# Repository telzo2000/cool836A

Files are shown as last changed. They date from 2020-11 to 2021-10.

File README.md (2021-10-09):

# cool836A
ブラックバージョン(Ver.A)のbuilde guideはこちらです。<br>
https://github.com/telzo2000/cool836A/blob/master/buildguide_black.md
<br>
レッドバージョン(Ver.B+)のbuilde guideはこちらです。<br>
https://github.com/telzo2000/cool836A/blob/master/buildguide_red.md
<br>
イエローバージョン(Ver.C+)のbuilde guiadeはこちらです。<br>
https://github.com/telzo2000/cool836A/blob/master/buildguide_yellow.md
<br>

# 設計に至るまで（Up to the design）
<br>
平成31年度および令和元年度に、「自作キーボード」という語を知りました。<br>
その後、nomu30、Choco60、Caravelle等を購入して実際に作ってみました。<br>
これらはどれもとても素晴らしいキーボードでした。<br>
次にSU120を知り、文系の自分でもなんとか自作キーボードが作れるのではないかと考えるようになりました。<br>
実際、SU120をTALP KEYBOARDさんで購入して、それを使って30%キーボード「My First Mini」を作りました。<br>
なかなかうまくいなかい部分があり、その際にはSU120の作者さんから助言をもらい、
完成に至りました。<br>
この経験を積んで、さらにSU120を使い、Caravelleのあまったスイッチプレートを活用した「Caravellion」を作りました。<br>
「Caravellion」と同時期に、格子配列の30％キーボード
[cool635](https://github.com/telzo2000/cool635-) 
を作りました。<br>
さらに30％キーボードに、矢印キーや数字キーが欲しいと思い始めて、50％キーボード「cool753」を作りました。<br>
これらはすべてSU120を使って作りました。<br>
ここまで経験すると、ある程度、わかってきたもので、次は何を作ろうかなと思い、
何となく知ったAlice配列という言葉が気になり、多分Alice配列っぽいだろうと考えて作ったのは、
30％キーボードの「cool836A」です。<br>
これは令和２年度の７月に、４連休を利用して一気に作りました。<br>
ただ、レイアウトについては事前に、角度を５〜10の間で試行錯誤しています。<br>
これまでの経験から、ケースはMDF材ですばやく加工することができるようになりました。<br>
ただ、私の技術では、木材で作成すると、やや大きくなってしまいます。<br>
cool635の作成で、kicadの使い方も少しわかってきたので、cool836Aも最初はSU120で作り、
次にkicadでPCBの設計をしました。<br>２度のPCBを発注しました。<br>
１度目は基板部分のみ、２度目は基板、トッププレート、ボトムプレートをまとめたもの。<br>
試作用cool836Aは１度目の基板部分のみに、発注先のミスにより余分に頂いたボトムプレートから成るものです。<br>
頒布用cool836Aは２度目のまとめたものに成るものです。発注したPCBが黒色だったため、通称「ブラックバージョン」としています。<br>
「レッドバージョン」は、MXソケットを採用しました。pro microとの部品干渉から、一部のキースイッチは前後向きを変えました。<br>
PCDの下面にLEDを追加できるよう端子を加えましたが、まだQMKの理解が進んでいないため、私自身は使えません。<br>
発注先の問題より、イエローバージョンの到着に１ヶ月かかりました。仮組みした段階で、複数の課題が見つかりました。<br>
1つ目はpro microの位置が2mmぐらいの差でコンスルーの足とキースイッチの端が干渉しています。<br>
2つ目は、ケーブルをつなぐ間口が狭かったことです。細いケーブルであれば問題ありませんが、私が普段使っているケーブルだと干渉してしまい刺さりません。<br>
将来の予定としては、イエローバージョンの修正版を発注するつもりです。その際、合わせてレッドバージョンを黒色で発注するつもりです。<br>
12月27日に、レッドバージョンの黒色として、一部のネジ穴（M２スペーサー）の大きさを修正したVer.Dを発注しました。これに合わせてアクリルでのトッププレート、ボトムプレートも発注しました。<br>
令和３年１月上旬に、Boothにてイエローバージョン、アクリルプレートをそれぞれ頒布した。
令和３年１月中旬、フライングオニオオハシ氏（＠oha_oha_Ohashi）により、qmk_firmwareへのマージがなされ、qmk configuratorでもキーレイアウトの変更が可能となった。フライングオニオオハシ氏、本当にありがとうございました。<br>
余談ですが、一部の修正をラズパイで行うことができました。<br>
しばらくcool836Aについてのアップデートをしませんでした。ブルートゥースに向けて試行錯誤をしましたが、まだ成功していません。<br>
cool943Sの開発が終わり、発注した後、時間ができたので、ラージサイズのcool836Aを設計しました。当初、Alice配列の分割キーボードを想定していました。しかし、それより先に一体型を作ろうと思い、ラージサイズ版のcool836A、正式には[cool844](https://github.com/telzo2000/cool844)となり、44キーの40％キーボードとなりました。そのケースについては、GH60系のケースが使えるように設計しました。MCU直付けの基板を作るのはちょっと難しく、ちょっとした工夫で乗り切ろうとしています。令和3年2月22日に発注しました。<br>
（令和３年10月）Raspberry財団がRaspberry Pi Picoという、安価な部品を作ったので、それを使ったcool836Aを設計した。<br>
 pro microよりも、Picoのほうがやや長く、幅もやや広いため、従来の設置場所では困難と感じたため、設置場所を変更して設計した。それに合わせて配線の見直しをしました。これまでcol,rowで6x6で組んでいた部分を、12x3で組んでみました。特に問題なく、やや配線が綺麗にできたというところです。<br>
 Raspberry Pi PIco採用のcool836Aを、cool836Picoと名付けて、kmkによるpythonで、それと別にprkによるrubyで、それぞれファームウェアを作成した。この時点では、qmkが大きく先んじている。kmkもprkも、期待した以上に使い勝手が良くない。レイヤーキーあたりの反応がちょっとゆっくりと感じている。もう少し洗練されないと、日常使う気持ちになれない。ただ、ハード的なことはわかったので、今後、cool836A以外にも、Raspberry Pi Picoを使った自作キーボードを設計しようと思う。

# 今後の変更予定（Update Plan)
順不同<br>
☑︎REMAP対応に向けて、via用jsonファイル、hexファイルの作成<br>
※この」リポジトリ内にあります。ご自由にお使いください。<br>
☑MXソケット採用 Ver.B Date:20201024<br>
☑︎chocoスイッチ版　※pro microの設置場所をPCBの下面から上面に変更か<br>
☑LED装着　Ver.B+ Date:20201025<br>
※装着して点灯を確認。（2020/12/25）<br>
□pro micro→MCU直付<br>
☑アクリルのトッププレート、ボトムプレート　※試作PCBの余剰分（３枚）に使用するか。（2020/11/14）<br>
※Ver.Dで発注した。（2020/12/27）<br>
□アクリル密閉型ケース<br>
☑ラージ版（仮称cool840A）※ラージ版のcool836Aはcool844という名称となりました。[別のリポジトリ](https://github.com/telzo2000/cool844/blob/main/README.md)にまとめました。<br>
☑薄型への挑戦（pro microの位置変更）※イエローバージョンとして計画中(2020/11/10)<br>
□iPhone固定できるケースをオプションとして作る（アクリルか？）<br>
□Bluetooth採用※よくわかっていませんが、イエローバージョンまでならば、多分電池を収納するスペースがあるだろうと考えました。思いつきです。青色にして「ブルーバージョン」となるかな。<br><br>
☑BLE micro使用時の電池ケース収納部分を追加（2020/11/11）※イエローバージョンで実装済み。<br>
☑︎Raspberry pi picoに対応したバージョン<br>

# 発注ガーバーファイル名
試作　gbr　（20200812）<br>
Ver.A gbr20200901　通称「ブラックバージョン」<br>
Ver.B+ gbr20201025　通称「レッドバージョン」<br>
Ver.C+ gbr20201114　通称「イエローバージョン」<br>
Ver.D　gbr20201227plate,gbr20201227pcb,gbr20201227case<br>
cool844 Ver.1 gbrcool844date20210222 通称「cool836Aラージサイズ」<br>

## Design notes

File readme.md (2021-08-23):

# cool836A

- このプロジェクトの詳細については設計者たる[m.ki様](https://twitter.com/0002ozlet)による[GitHubリポジトリ](https://github.com/telzo2000/cool836A)の記述をご覧ください。

### バージョン(A, B+, C+)について
- m.ki様によるとどのバージョンも回路は同じで、ファームウェアを分ける必要はないとのことです。
- しかしながらこのファームウェアは、cool836A ver.B+ (通称レッドバージョン)のみでテストされています(2021年1月7日現在)。そのため念のため、当面の間はサブフォルダの名前をcool836A/verB_REDとさせていただきます。
- ほかのバージョンに書き込んだときに不具合等がありましたら、方はお気軽に私[オオハシ](https://twitter.com/oha_oha_Ohashi)までご連絡ください。

## 申し訳程度のチュートリアル
詳細に書き込む労力は払えませんでしたが、最低限のコードのみ記します。

git clone のあと、

``` make cool836A/verB_RED:default ```

でコンパイル可能であることを確認し、

``` make cool836A/verB_RED:default:avrdude ```

によってデフォルトキーマップをPro Microに焼けるかもしれません。
`default`の代わりに`Ohasheen`を利用することもできます。

初心者の方はもっと素晴らしいウェブサイトでGitやqmk firmwareの使い方を覚えていただくのがよいかと思います。

-----------------
## English
- [Here](https://github.com/telzo2000/cool836A) are a full description of this project and build guide by the great Designer: [m.ki](imgur.com image replace me!)

- Each virsions(A, B+, C+) of cool836A has the same circuit and that means you can install this firmware on any of them.
- However, this repository is currently(Jan 7, 2021) tested on ver.B+ (RED version) only. Feel free to contact [ME](https://github.com/ketcha-k) for any problems.

- firmware maintainer: [Ohashi](https://github.com/ketcha-k)

## Such a humble tutorial
The author would like to provide a minimum guide.

After cloning the repository, you may want to 

``` make cool836A/verB_RED ```

to make sure it's compilable, and 

``` make cool836A/verB_RED:default ```

which leads you to the goal.

It is recommended that beginners learn how to get started with qmk firmware/configurator at other fantastic websites rather than here......

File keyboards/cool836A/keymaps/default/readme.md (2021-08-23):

# m.ki様によるデフォルトキーマップ

[レッドバージョン　ビルドガイド](https://github.com/telzo2000/cool836A/blob/master/buildguide_red.md)で紹介されていたキーマップです。チートシートを見ながらコードに書き写しました。

-------
## チートシート
以下、[同ページ](https://github.com/telzo2000/cool836A/blob/master/buildguide_red.md)の画像のコピーを添付します。
+ Layer=0
Layer=0
+ Layer=1
Layer=1
+ Layer=2
Layer=2
+ Layer=3
Layer=3

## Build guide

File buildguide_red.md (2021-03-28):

# レッドバージョン　ビルドガイド

**写真**



<br>
<br>
**特徴**
<br>
・30％Alice  layout<br>
・サンドイッチマウント、チルト0〜10度<br>
・PCB、トッププレート、ボトムプレートそれぞれFR4を使用。<br>
・36キー（MXソケットによるキースイッチ交換可能）<br>
<br>

**同封されている部品**
<br>
１　PCB　１枚<br>
２　トッププレート　１枚<br>
３　ボトムプレート１式（４枚）<br>
４　ダイオード　40個（予備４個を含む）<br>
５　タクトスイッチ　１個<br>
６　ネジ（M2 4mm）　　７本<br>
７　ネジ（M2 8mm）　　７本<br>
８　スペーサー（M2 10mm）　７本<br>
９　クッションゴム　４個<br>
１０　MXソケット　40個（予備４個を含む）<br>
<br>

**別途、購入が必要な部品**
<br>
１　キースイッチ　36個<br>
２　キーキャップ　36個 ※１<br>
３　pro micro １個<br>
４　コンスルー（スプリングピンヘッダ）　１組（２個）<br>
※１　キーキャップの構成は、1U×32、1.25U×2、1.5U×1、1.75U×1ですが、全て1Uキーでも構いません。<br>
　　　キーキャップのレジェンド（キーキャップ上面の印字）とキーレイアウトのキーのサイズが一致しません。<br>
　　　レジェンドよりも使い勝手のよいキーレイアウトを優先しています。<br>
　　　<br>
**ファームウェア**
<br>
　「ハンダ付け不要版」では、すでに同封のpro microにファームウェアが書き込まれています。<br>
　このキーボードはQMKというキーボード用のソフトウェアで動作するようにプログラミングしています。<br>
　従来、頒布を目的としていなかったことと、作者が非IT系であることから、自力でファームウェアを作成していません。[Keyboard Firmware builder](https://kbfirmware.com/)を利用して、hexファイルを作成しました。[QMK Configurator](https://config.qmk.fm/#/)にプルリクする等すれば、QMKConfiguratorを使用してキーレイアウトを変更できますが、作者には、その力がありません。有識者の方で出来る方がいらっしゃれば、よろしくお願いします。<br>
　（もし、出来ましたら、ご連絡いただけると、ビルドガイドに、そのことを記載したいと思います）<br>
<br>
追記（令和３年１月16日）<br>
フライングオニオオハシ氏（＠oha_oha_Ohashi）によりqmk_firmwareへの公式マージがされました。そして、[QMK Configurator](https://config.qmk.fm/#/)にてキーレイアウトの変更、Jsonファイルをビルドができるようになりました。フライングオニオオハシ氏、本当にありがとうございました。<br>
<br>
　ここでは、Keyboard Firmware Builderで作成した、デフォルトJsonファイル（cool836default.json）とデフォルトHexファイル（cool836default.hex）を下記のリンク先に置きます。ダウンロードして、QMK Toolboxにて使用してください。QMK Toolboxは下記のリンク先にあります。<br>
　[QMK Toolbox](https://github.com/qmk/qmk_toolbox/releases)
<br>
　[デフォルトhexファイル](https://github.com/telzo2000/cool836A/)
<br>
　[デフォルトJsonファイル](https://github.com/telzo2000/cool836A/)
　<br>
　QMK Toolboxの使い方は詳しく書きませんが、デフォルトhexファイルをダウンロードして、「Local File」で選択してください。pro microをPCに接続し、リセットボタンを押して書き込みます。（リセットボタンをダブルクリックしないと書き込めないパターンのものもあります）<br>
　書き込み方法などは[サリチル酸さんの（初心者編）自作キーボードにファームウェアを書き込むの記事](https://salicylic-acid3.hatenablog.com/entry/qmk-configurator)がとても参考になります。他にも有用な記事が多いので、一読することをお勧めします。<br>
　デフォルトキーマップは作者が実際に使用しているもので、ほぼ何不自由なく使えるように工夫しています。チートシートは次のとおりです。<br>
Layer=0<br>
cool836Alayer0
<br>
Layer=1<br>
cool836Alayer1
<br>
Layer=2<br>
cool836Alayer2
<br>
Layer=3<br>
cool836Alayer3
<br>
　キーレイアウトの変更をされる場合は、事前に、[デフォルトJsonファイル](https://github.com/telzo2000/cool836A/)をダウンロードしてから、[Keyboard Firmware builder](https://kbfirmware.com/)へアクセスしてください。「Upload」をクリックして、先ほどのデフォルトJsonファイルを選択してください。下の画面になりましたら、「KEYMAP」をクリックしてください。その画面でキーレイアウトの変更ができます。<br>
kfbscreenshot1
<br>
　（「WIRING」「PINS」は絶対に変更しないでください。ここを変更して作成したHexファイルでは正しくキーが入力されなくなります。）変更ができましたら、「SETTING」をクリックしてください。下の画面になりましたら、「Save Configuration」をクリックしてください。変更されたキーレイアウトのJsonファイルがダウンロードされます。次回以降、それを使うことで、変更履歴を意識しながら、最高のキーレイアウトへ到着できると思います。<br>
kfbscreenshot2
<br>
　続いて、「COMPILE」をクリックしてください。下の画面になりましたら、「Download .hex」をクリックしてください。変更されたキーレアウトのHexフィルがダウンロードされます。このHexファイルを前述のQMK Toolboxで使用してください。<br>
kfbscreenshot3
<br>
<br>
**LEDについて**
<br>
　実装できるように、PCB下面に配線はしました。自己責任でお願いします。<br>
 20201226追記：私自身のレッドバージョンに実装してみました。<br>
 
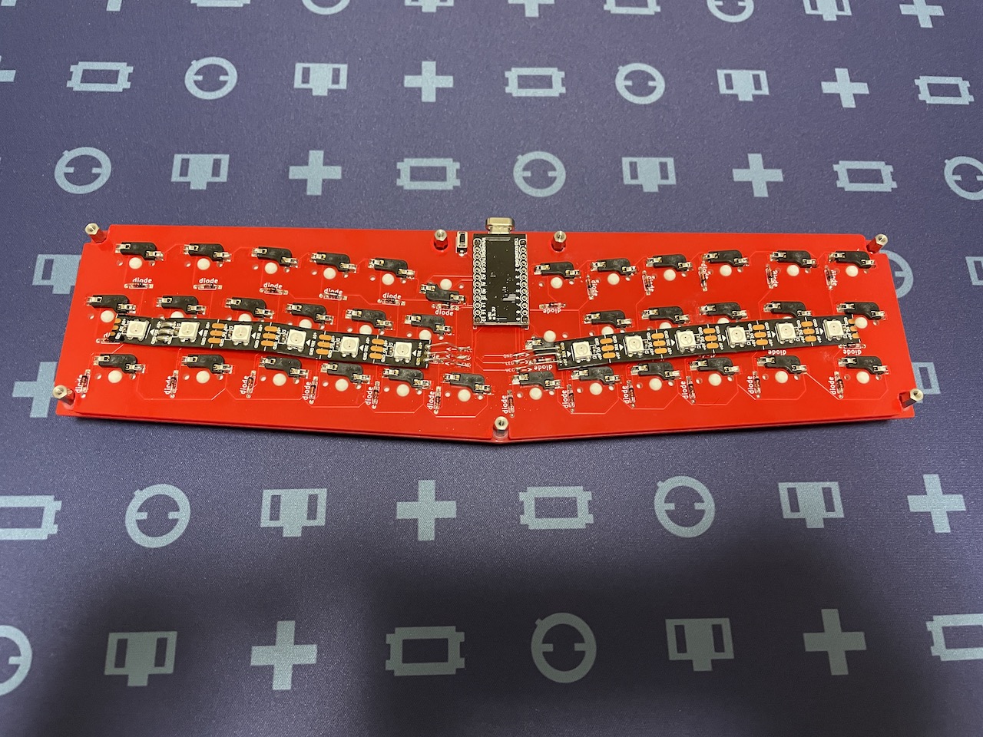
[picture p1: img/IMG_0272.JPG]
 
 <br>
 [Keyboard Firmware Builder](https://kbfirmware.com/)で、LEDの処理ができるようになりましたので、それに合わせて、LED対応したファームウェアを作りました。Layer３にLEDのオンオフに関するキーを追加しました。LED対応のJsonファイル（cool836LED.json）とHexファイル（cool836LED.hex）を下記のリンク先に置きます。ダウンロードして、QMK Toolboxにて使用してください。QMK Toolboxは下記のリンク先にあります。<br>
　[QMK Toolbox](https://github.com/qmk/qmk_toolbox/releases)
<br>
　[LED対応hexファイル](https://github.com/telzo2000/cool836A/)
<br>
　[LED対応Jsonファイル](https://github.com/telzo2000/cool836A/)
　<br>
 私が実装したものは遊舎工房さんの「 [フルカラーシリアルLEDテープ 6個タイプ](https://yushakobo.jp/shop/a01sl-00/)」を２つ使いました。<br>
 
 Layer=3<br>
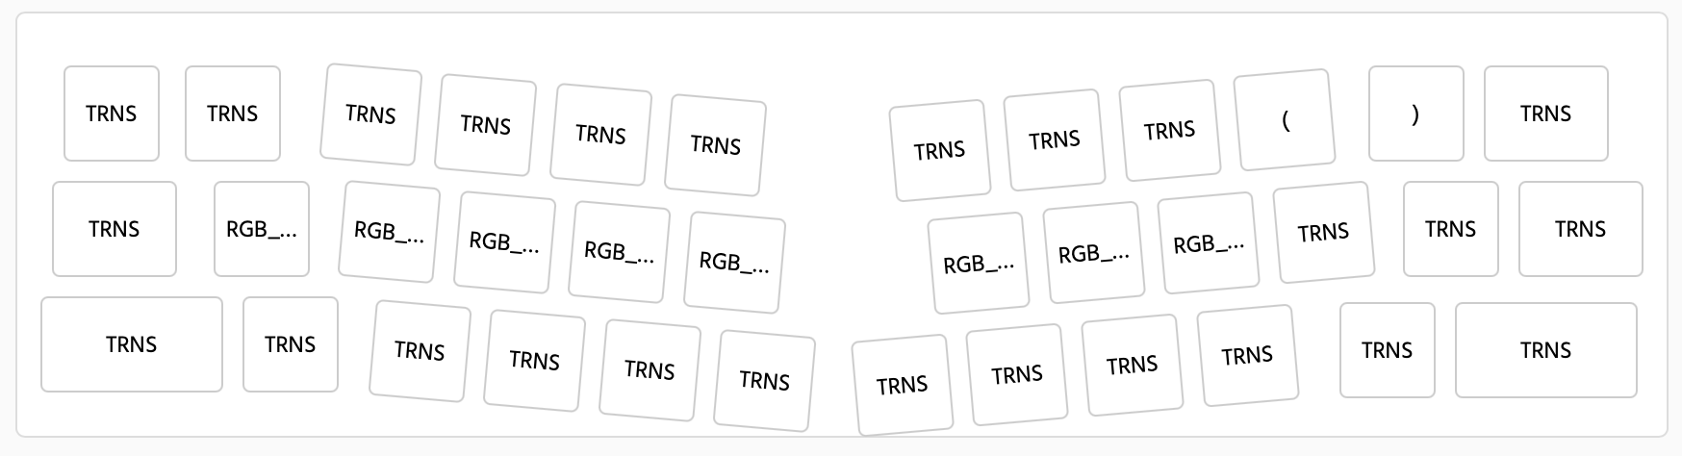
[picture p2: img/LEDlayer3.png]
 
<br>
<br>
**組み立て手順**
<br>
　ハンダ付け不要版では、２・３・４・５（ハンダ付け部分）の組み立て作業が済み、動作確認が完了しています。<br>
<br>
１　基板の確認<br>
　組み立ての前に、PCB、トッププレート、ボトムプレート１式の上・下面を確認します。全ての基板表面の右上に「cool836A」と印刷されています。印刷されている面が、上面となります。同じ位置になるように基板を重ねてください。上・下面が違うと、ネジが正しく入りません。<br>
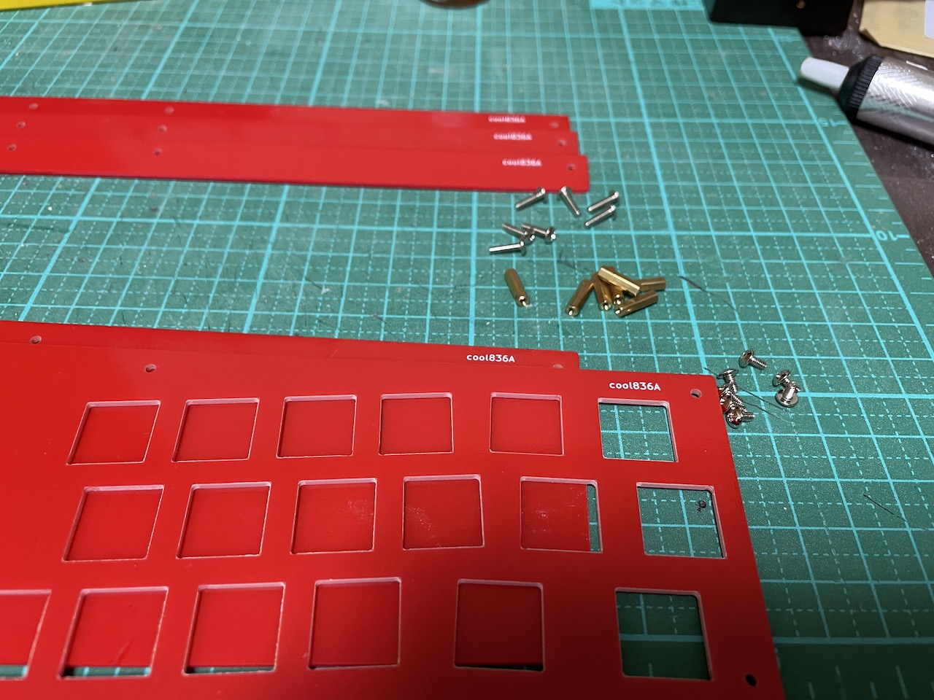
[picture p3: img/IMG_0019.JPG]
基板
　
　<br>
<br>
２　ダイオードのハンダ付け<br>
　ダイオードの足を曲げて取り付けて、ハンダ付けをします。ダイオードの足は、下面から「diode」と印刷された部分の穴に差し込みます。上面に伸びたダイオードの足は切り離してください。ダイオードには極性があります。ダイオードの黒い帯がある側が「diode」の文字の後ろになるようにハンダ付けしてください。ハンダ付けに自信がない場合、フラックスを利用すると、上手にハンダ付けができます。その後、フラックスクリーナーで綺麗に拭き取ることをお勧めします。<br>
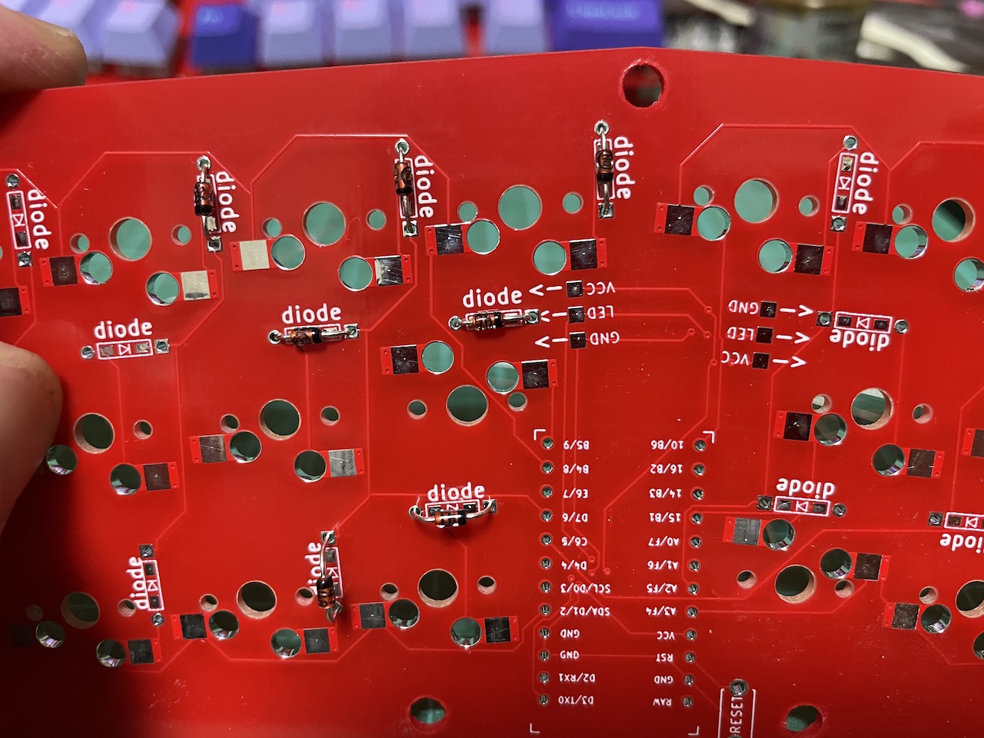
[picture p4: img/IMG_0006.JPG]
ダイオード

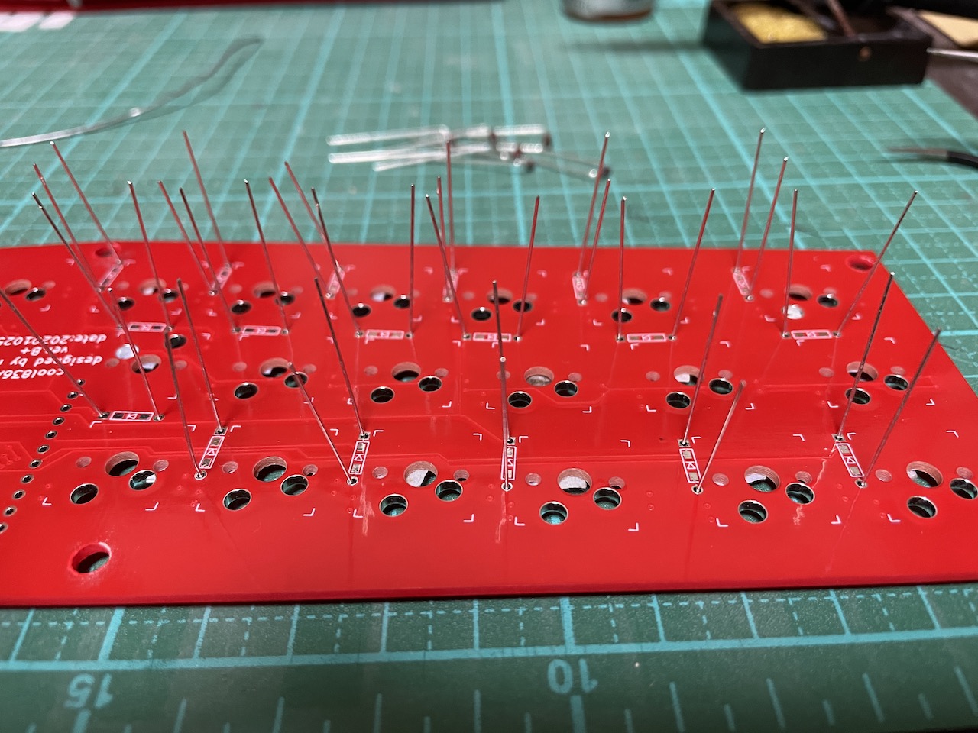
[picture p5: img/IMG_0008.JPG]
ダイオードハンダ付け

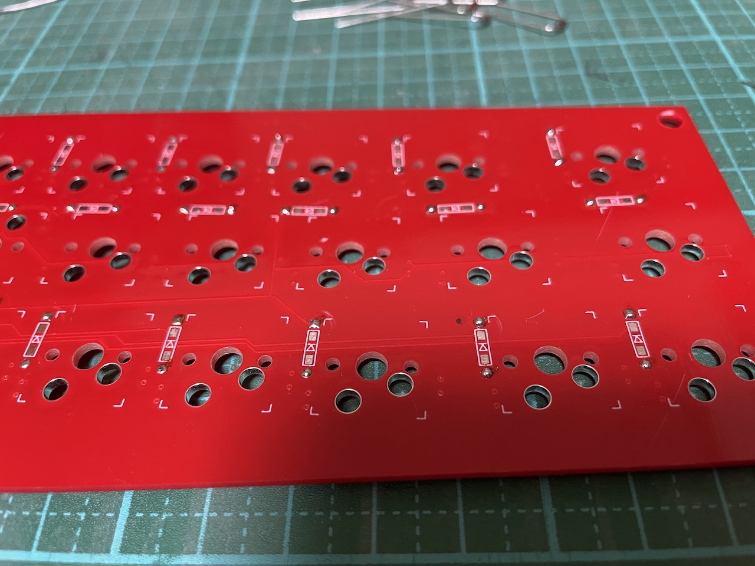
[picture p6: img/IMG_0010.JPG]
ダイオードハンダ付け２

<br>
<br>
３　MXソケットのハンダ付け<br>
　MXソケットをハンダ付けします。ソケットの向きに注意してください。ソケット両側の端子がPCBと接する方に、予備ハンダをしておくと、ハンダ付けが上手くいきます。上手くハンダ付けができない場合、フラックスを多めに塗布して行うと、ハンダがソケットの端子とPCBの端子の間に流れていきます。その後、フラックスクリーナーで綺麗に拭き取ることをお勧めします。<br>
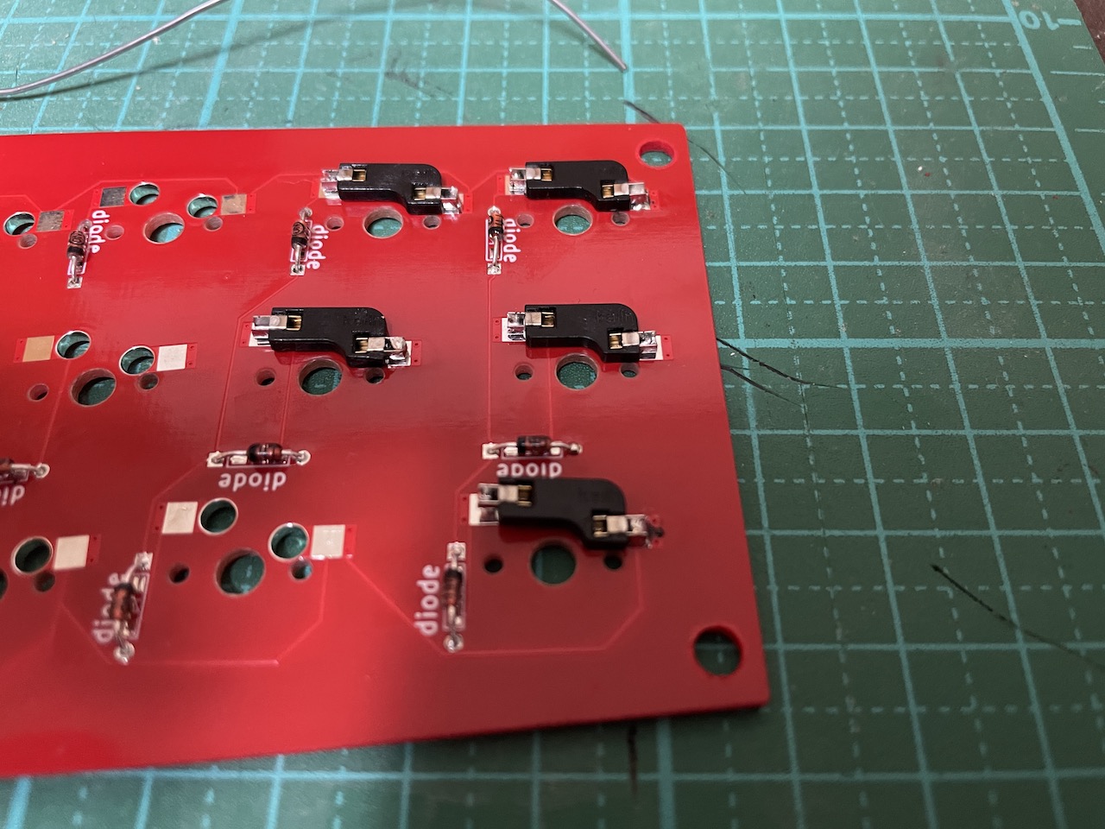
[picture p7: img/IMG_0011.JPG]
ソケットハンダ付け

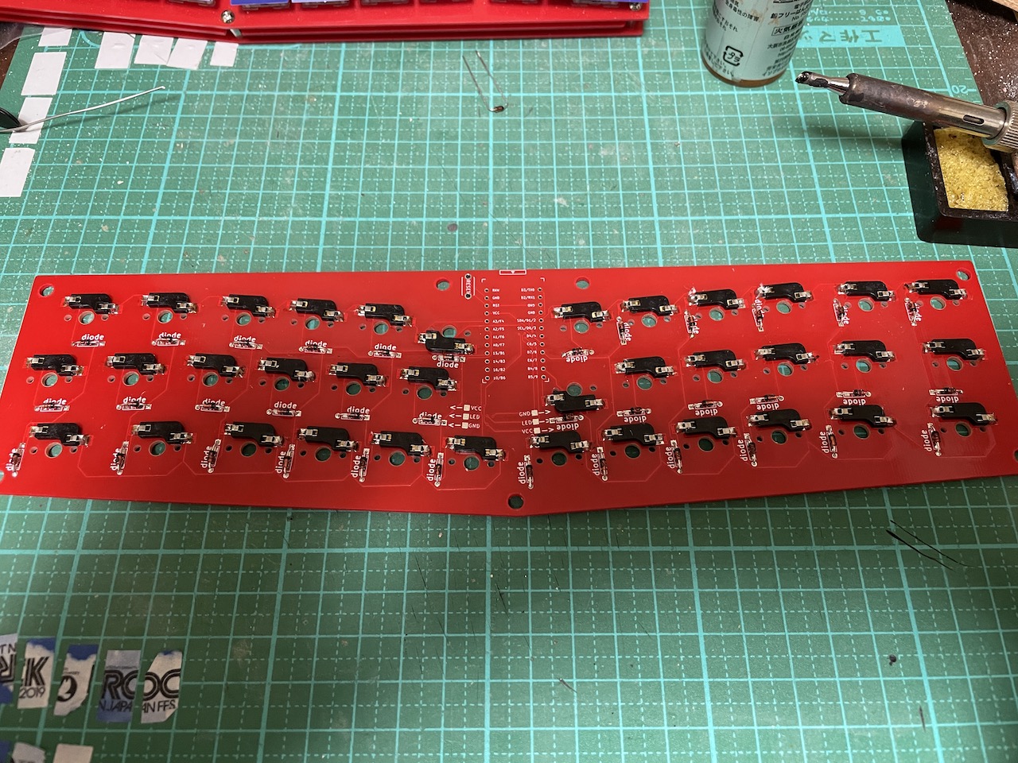
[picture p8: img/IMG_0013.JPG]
ソケットハンダ付け２

　<br>
　<br>
４　タクトスイッチの取り付け<br>
　タクトスイッチをPCB下面の「RESET」の印刷が隠れるように差し込んで、上面からハンダ付けをしてください。ここは上・下面を間違えると、後でトッププレートをつける時に、タクトスイッチが干渉します。<br>
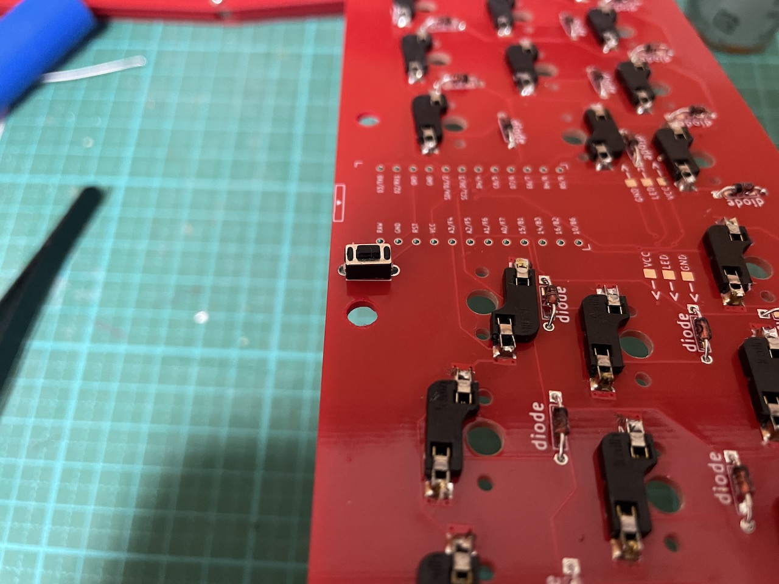
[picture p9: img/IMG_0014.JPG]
上面

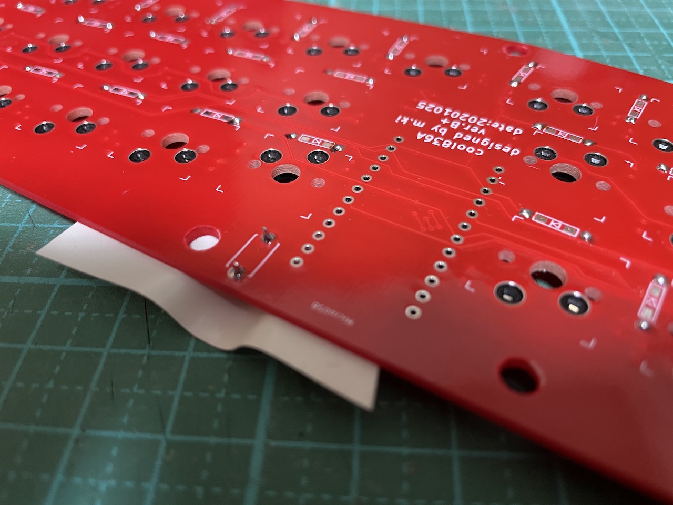
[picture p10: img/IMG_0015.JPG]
下面

　<br>
　<br>
５　pro microの取り付け<br>
　本製品ではコンスルー（スプリングピンヘッダ）を使用してのpro microの装着を推奨しています。コンスルー（スプリングピンヘッダ）の向きに気をつけて使用してください。画像を参考にして、pro microの向きに注意してください。<br>
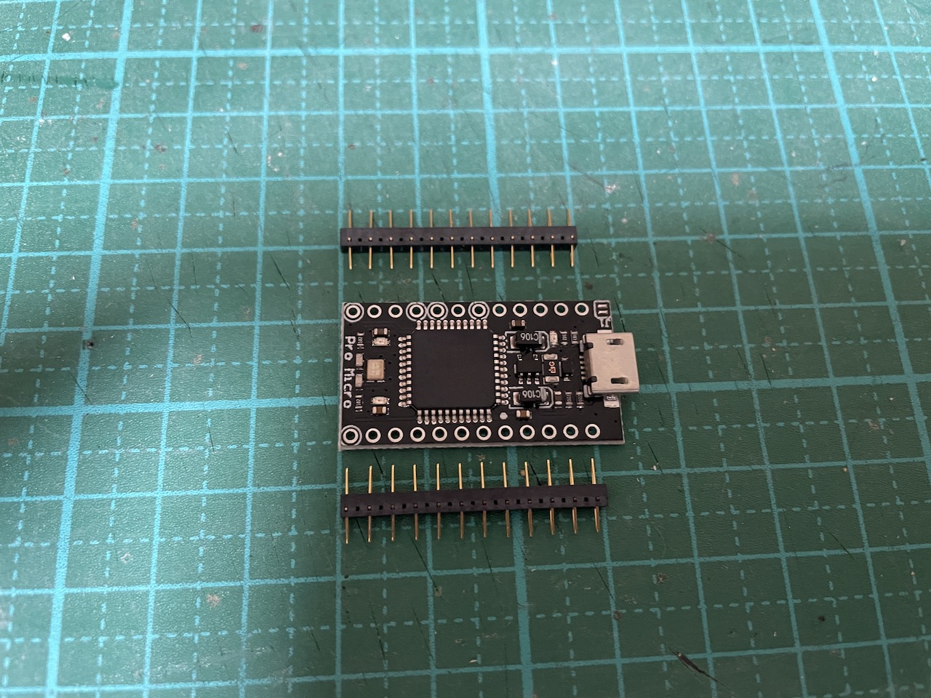
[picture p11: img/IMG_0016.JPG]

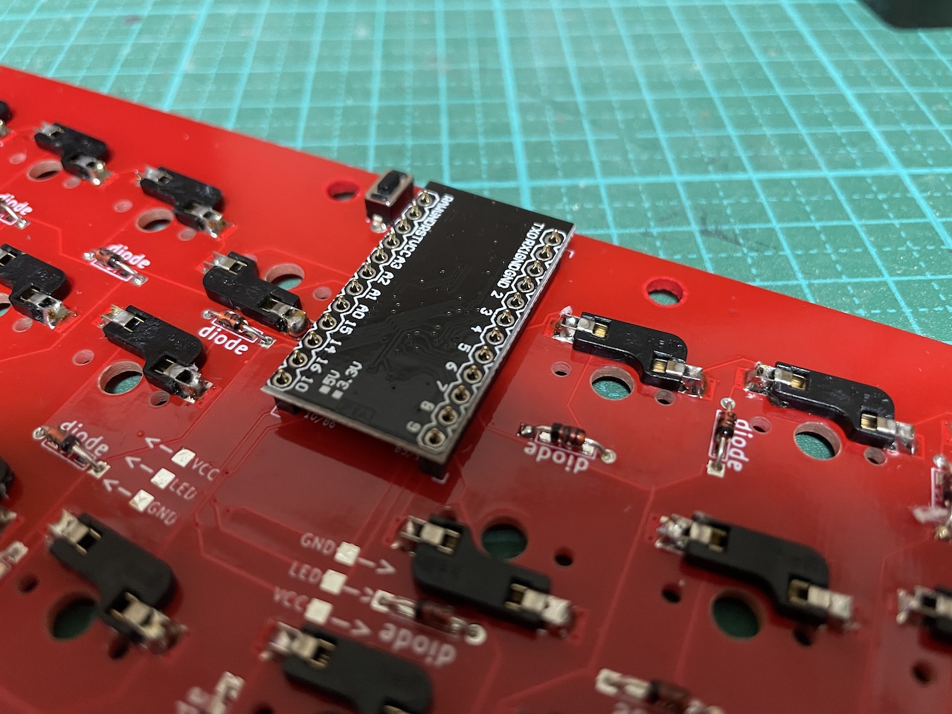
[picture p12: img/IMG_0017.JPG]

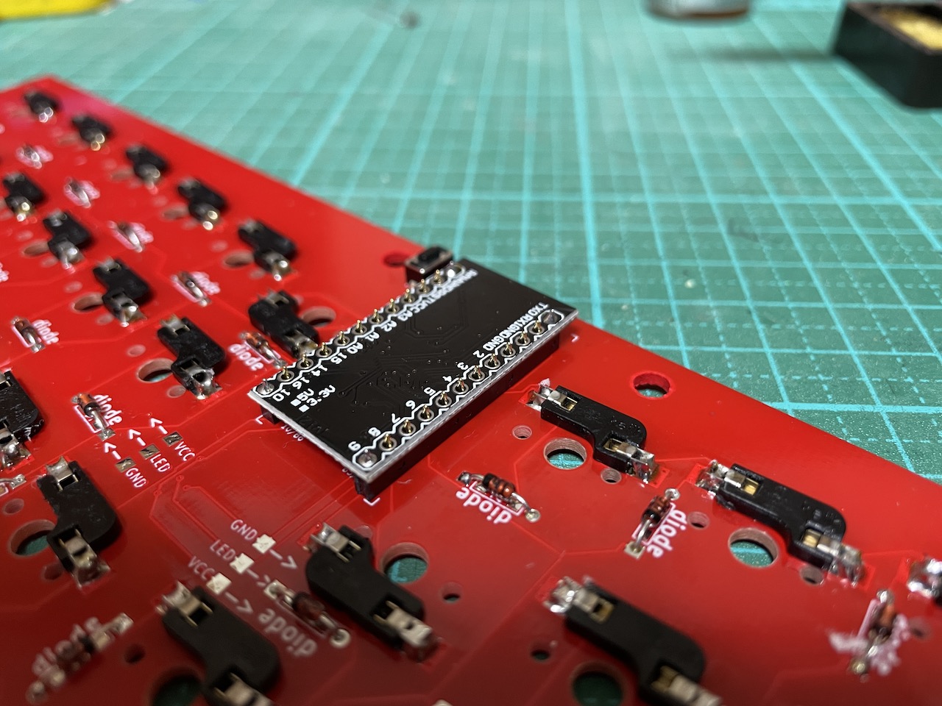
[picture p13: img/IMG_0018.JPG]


　コンスルーを使用しない時（pro micro付属のピンヘッダを使用する時）は、キースイッチの取り付け前に、PCBにピンヘッダのハンダ付けをしてください。キースイッチを取り付けた後では、できません。<br>
　<br>
　<br>
６　キースイッチの取り付け<br>
　最初にキースイッチ５個をトッププレートの５箇所（四隅と一番手前）に差し込みます。一度に全部のキースイッチを取り付けて、その後にPCBにハンダ付けしたMXソケットに差し込むとうまくいかないことが予想されます。５箇所で一度PCBにハンダ付けしたMXソケットに差し込み、残りのキースイッチをトッププレート、PCBの順に差し込んでください。それぞれのキースイッチの足がきちんとMXソケットの基板の穴に差し込まれていることを確認してください。差し込むときに、足が曲がってしまうことがあります。その場合は、ボタンを押しても入力されません。一度キースイッチを外して、足の修正または新しいキースイッチに交換等対処してください。<br>
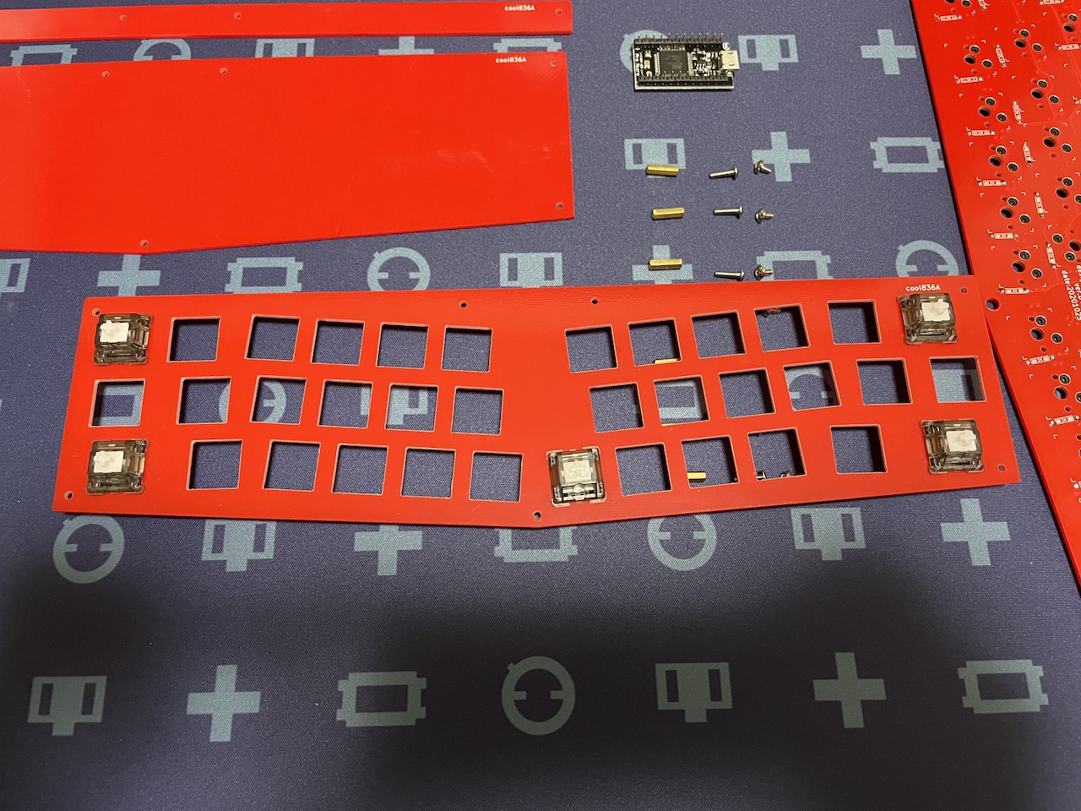
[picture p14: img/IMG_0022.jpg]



<br>
<br>
７　トッププレート、スペーサーの取り付け<br>
　トッププレート上面7箇所のネジ穴からM2ネジ4mm（短い方のネジ）を差し込み、スペーサーで固定します。<br>
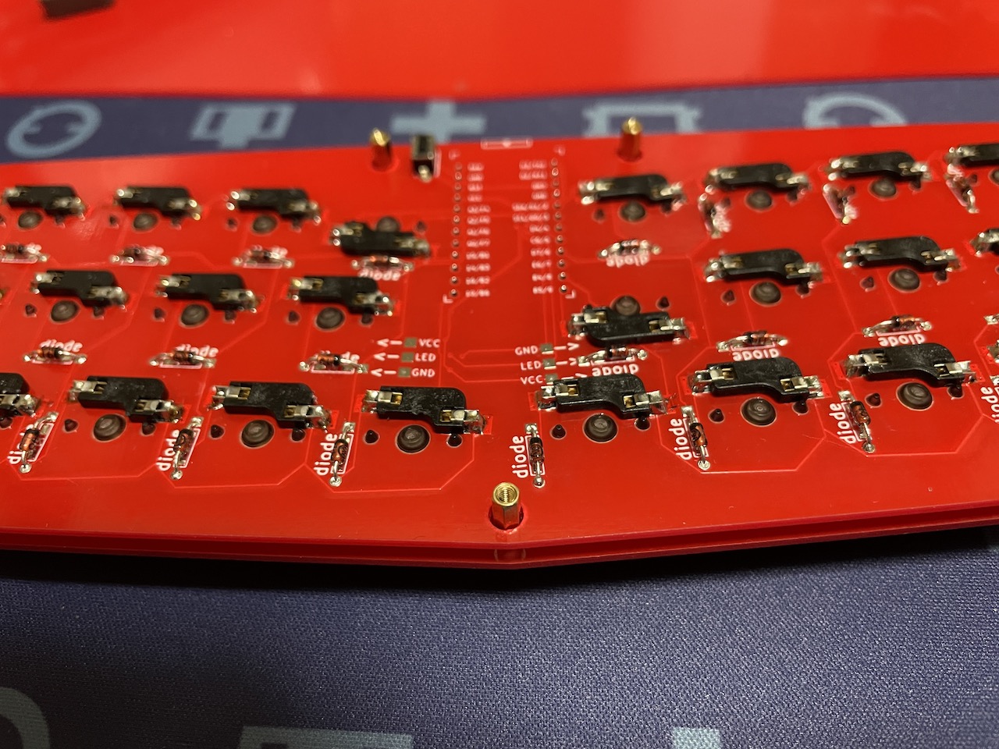
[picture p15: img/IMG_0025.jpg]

<br>
<br>
８　ボトムプレートの取り付け<br>
　ボトムプレート1式は次の４つパーツで構成されています。<br>
- ボトムプレート大　１枚
- ボトムプレート小　３枚
<br>
　ボトムプレートのネジ穴からM2ネジ8mm（長い方のネジ）を差し込み、トッププレートに装着されているスペーサーで固定します。<br>
　このキーボードは、ボトムプレート小を１〜３枚使用することで、最大10度ぐらいの傾斜を付けることができます。また、ボトムプレート小を使わないと、傾斜のないフラットなキーボードになります。試してみて、最適な角度で使用してください。


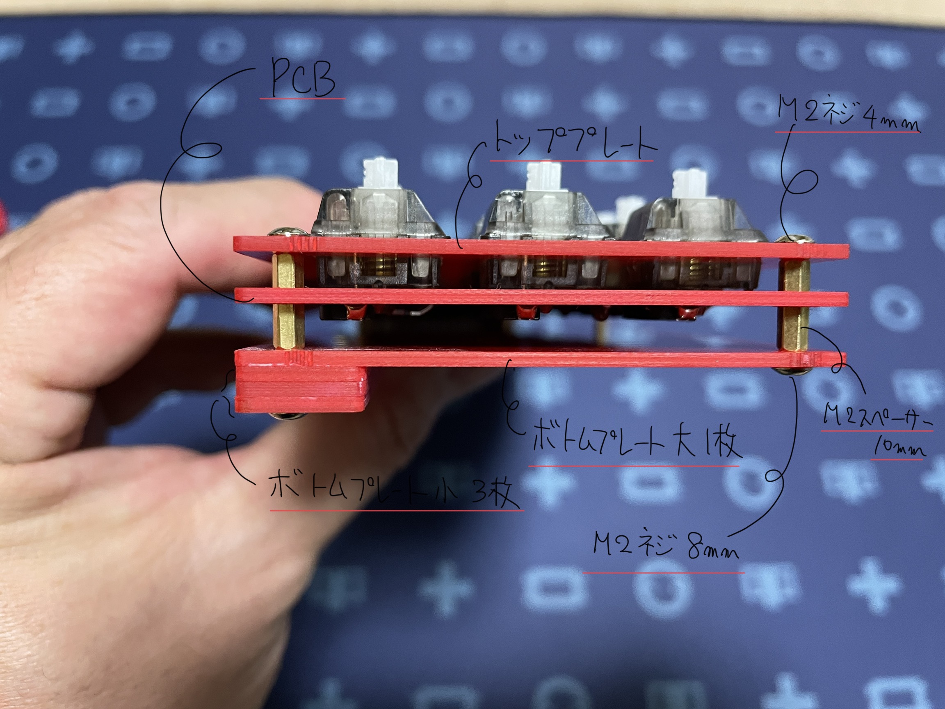
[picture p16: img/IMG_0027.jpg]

<br>
その後、お好みでクッションゴムを取り付けてください。<br>
<br>
組み立ての手順は、以上です。<br>
<br>
気に入っていただけたら、幸いです。　<br>

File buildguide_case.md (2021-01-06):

# アクリルケース換装の手順
<br>

**写真**
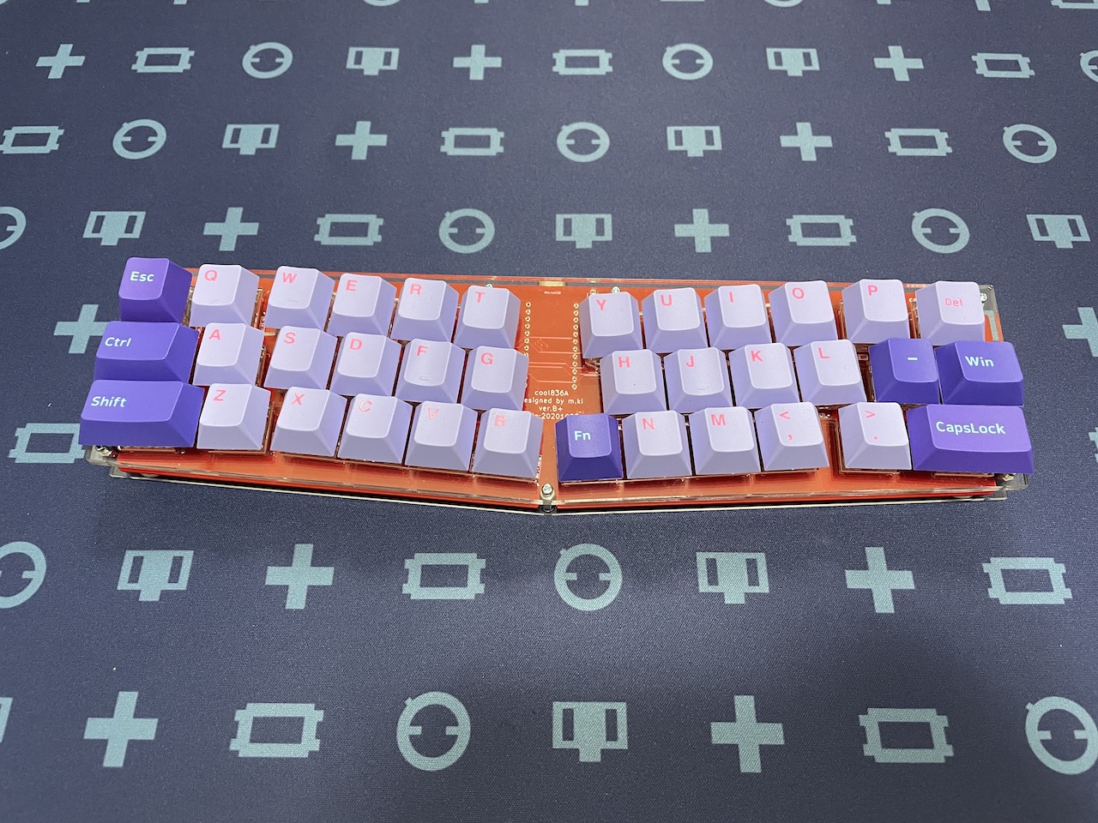
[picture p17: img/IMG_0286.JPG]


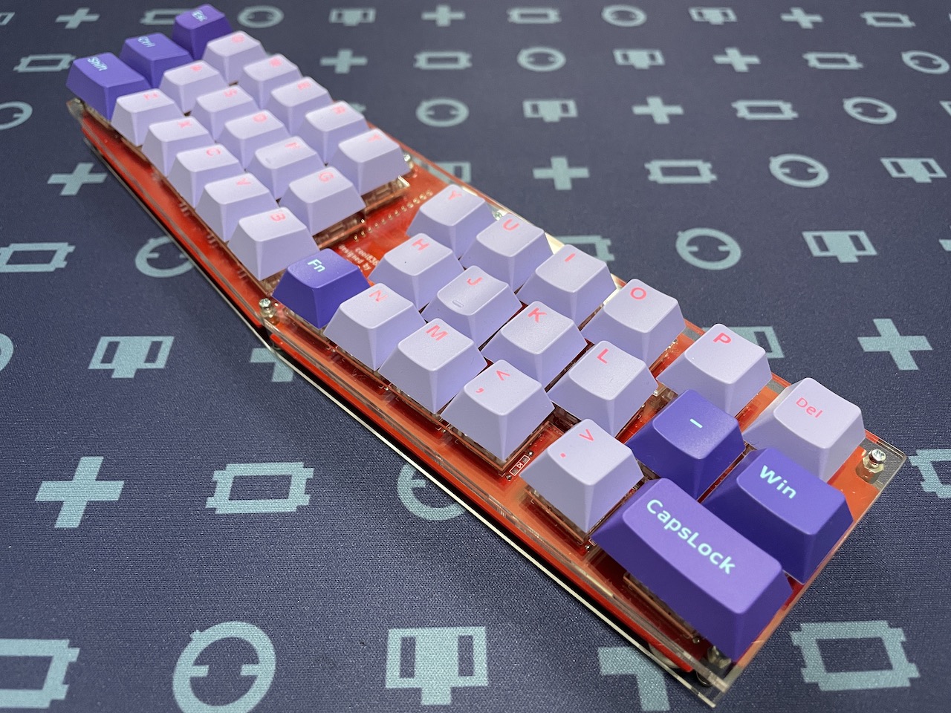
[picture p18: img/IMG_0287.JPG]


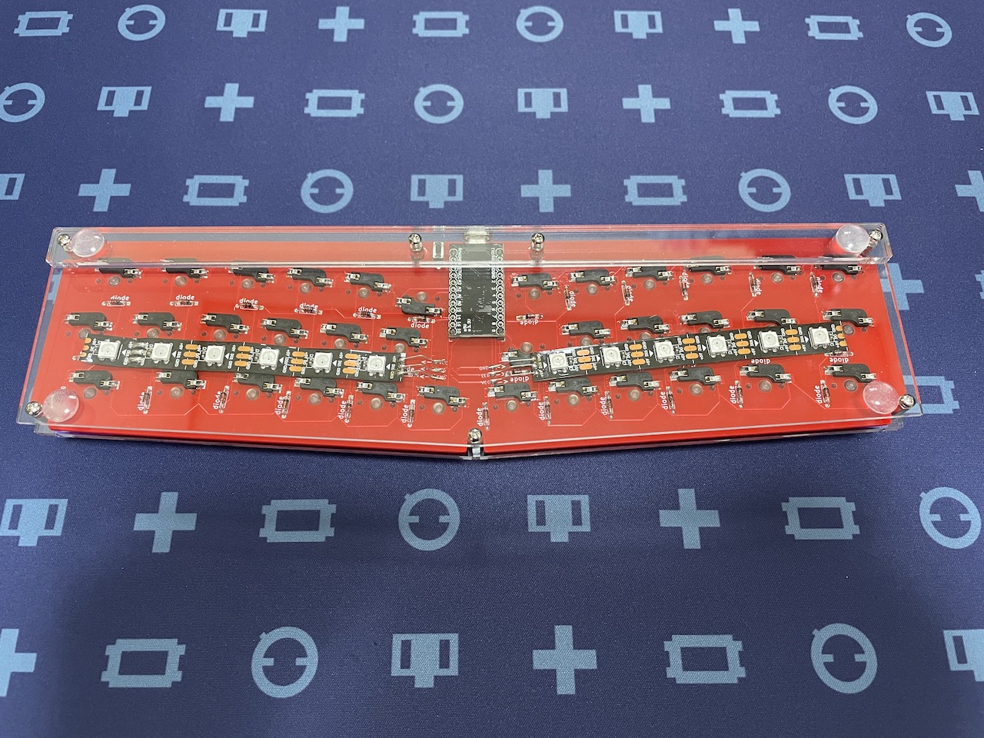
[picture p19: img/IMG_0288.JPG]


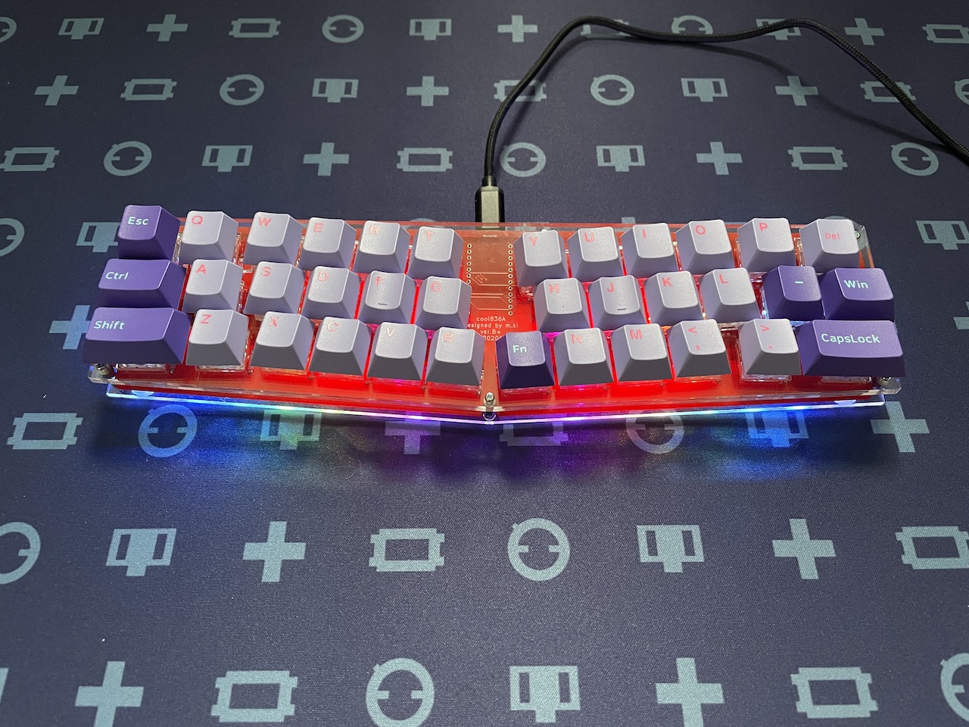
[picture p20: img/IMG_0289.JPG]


<br>

<br>

# 注意

　本品は、m.kiが頒布している自作キーボドキット「cool836Aレッドバージョン」用のアクリルケースです。本品には、PCB等が含まれていません。
すでに、cool836Aレッドバージョンをお持ちの方が対象となります。なお、cool836Aブラックバージョンをお持ちの方は、組み立て前であれば、
トッププレート等と本品と交換して使用することが可能です。組み立て後であれば、一度、PCBにハンダ付けされたスイッチを取り外す手間があります。
本品は、レッドバージョン以降に、実装されたLEDの透過のために設計されたものであります。LED実装のないブラックバージョンには不向きと考えています。
なお、cool836AにおけるLEDはオプションです。別途購入が必要となります。
cool836Aイエローバージョンとの互換性は未確認です。
<br>
<br>

**同封されている部品**
１　トッププレート　１枚 <br>
２　スイッチプレート　１枚 <br>
３　ボトムプレート大　１枚 <br>
４　ボトムプレート小　２枚 <br>
５　M２ネジ（８mm）　７本 <br>
６　クッションゴム　４個 <br>
<br>

**換装の手順**
<br>
１　レッドバージョンのネジを外して、部品ごとに分けてください。次の写真では、比較できるよう並べました。<br>

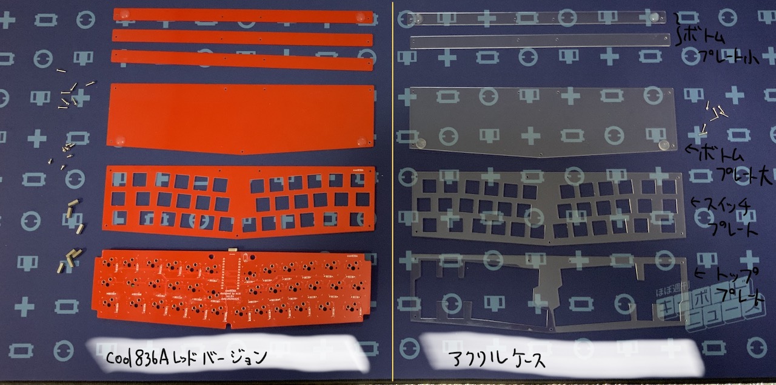
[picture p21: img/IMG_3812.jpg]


使うのは、次の写真にある部品です。<br>

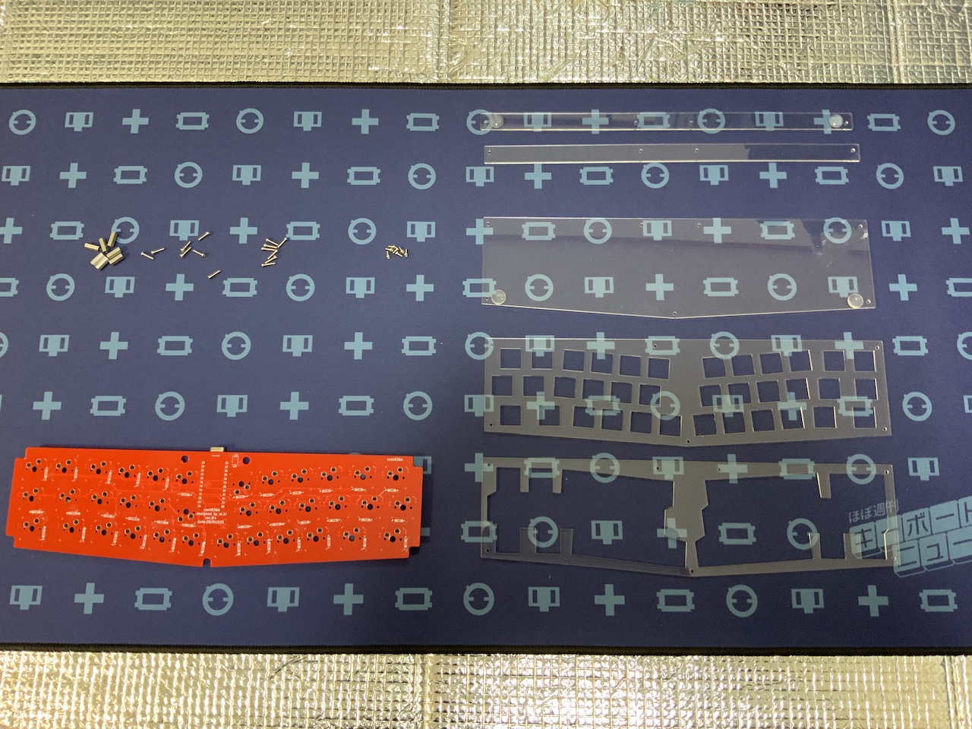
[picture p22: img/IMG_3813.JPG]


２　アクリルのトッププレートとスイッチプレートを重ねて、トッププレート側からM２ネジ（８mm　※本品では８mmしか使用しません。レッドバージョン付属の４mmは不要となります。）を差し込み、
反対側にM２スペーサーで固定します。<br>
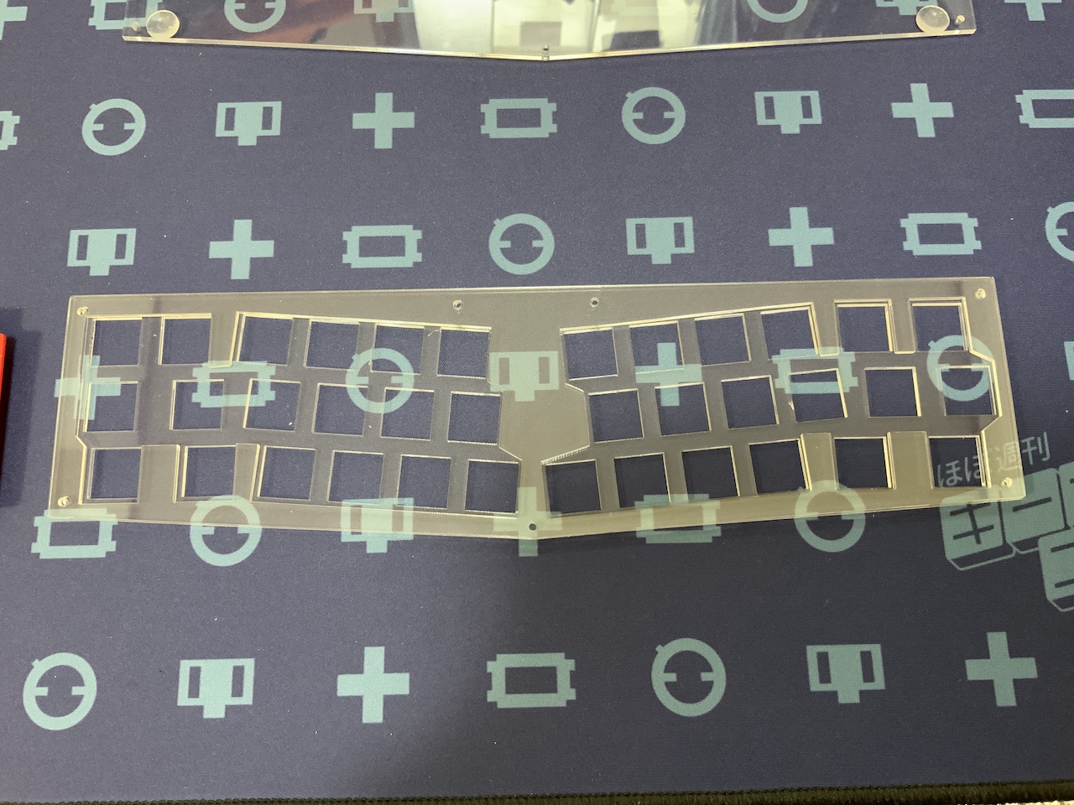
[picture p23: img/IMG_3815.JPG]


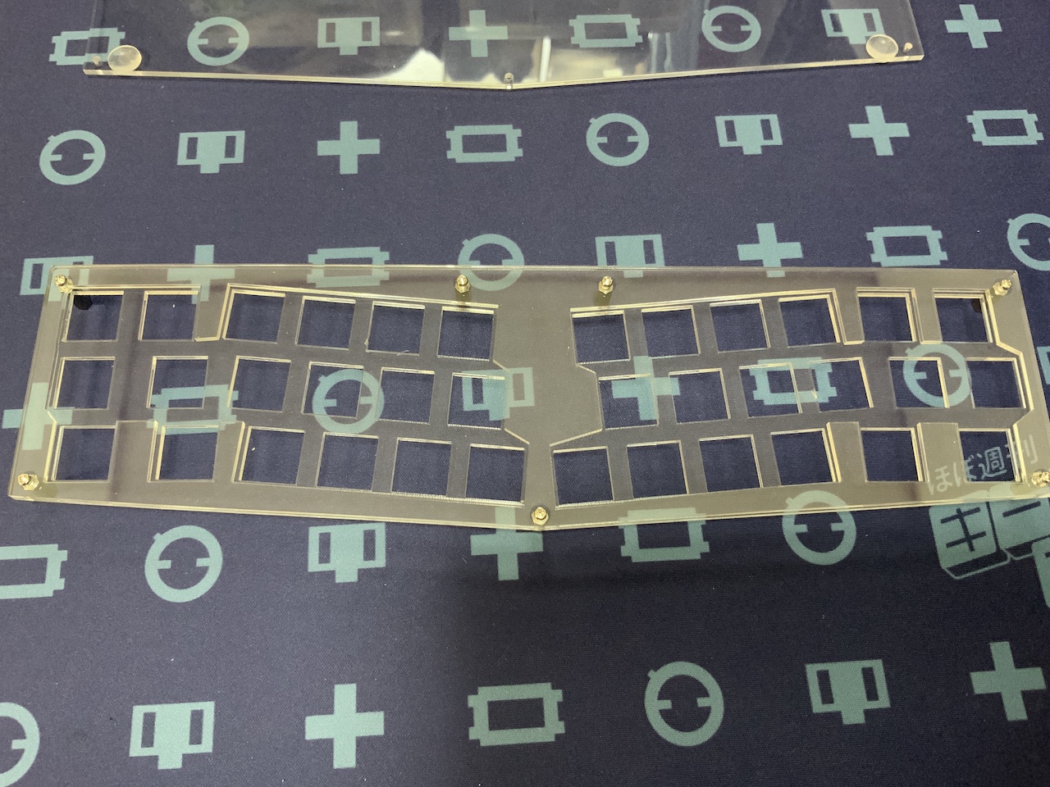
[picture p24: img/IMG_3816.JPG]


３　２でできたものにレッドバージョンPCBに重ねます。重ねたら、キースイッチをはめていってください。（写真ではキーキャップまではめた後の写真です。）<br>
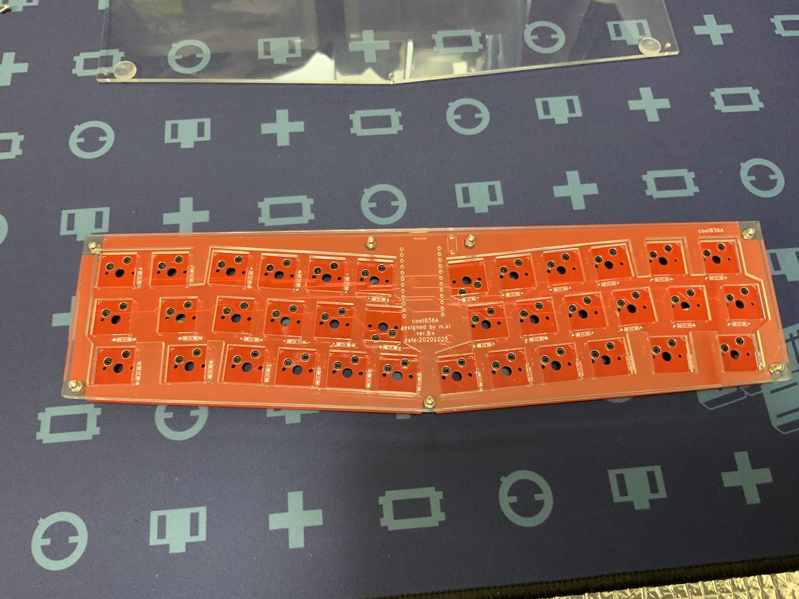
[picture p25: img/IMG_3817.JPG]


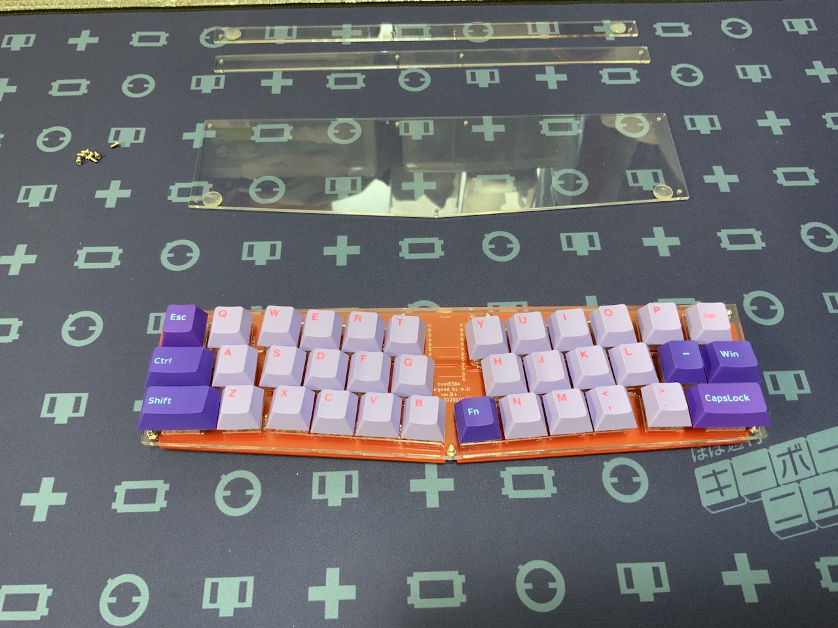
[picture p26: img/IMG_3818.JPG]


４　３の向きを逆さにして、ボトムプレート大、小を重ね、M２ネジで固定してください。クッションゴムを取り付ければ、完成です。（写真では、先に取り付けてあります。）<br>

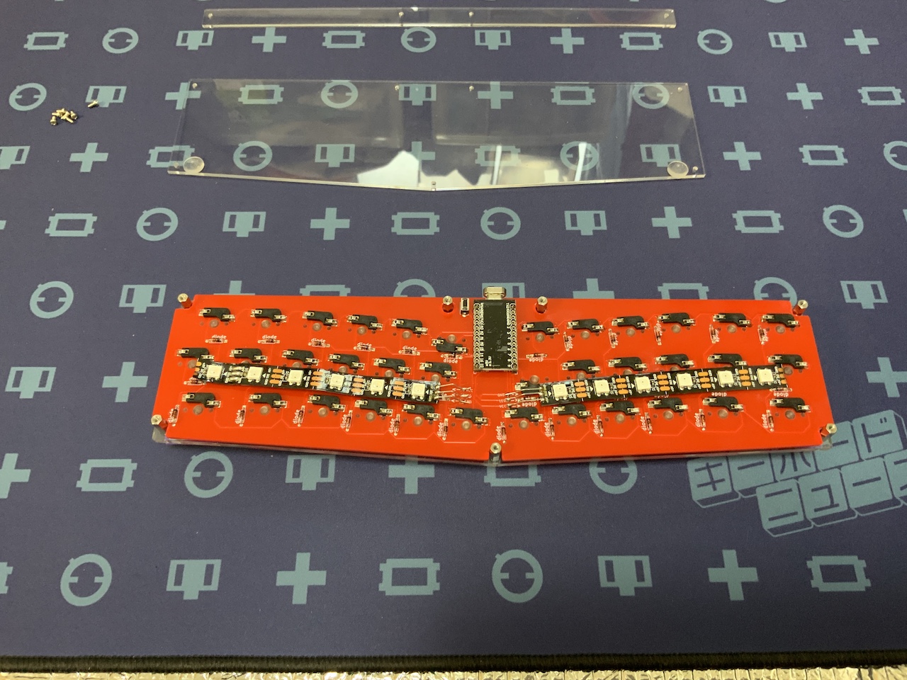
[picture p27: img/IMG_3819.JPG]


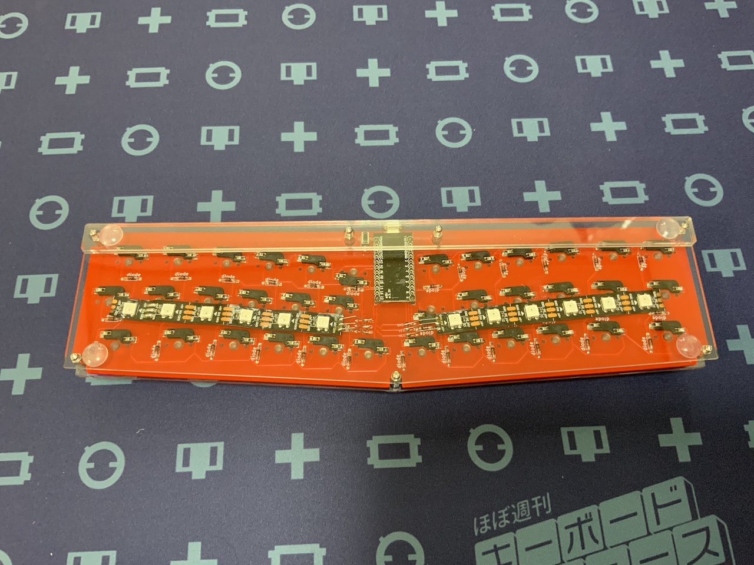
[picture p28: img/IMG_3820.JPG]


気に入って頂ければ、幸いです。

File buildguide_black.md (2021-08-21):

**写真**




**特徴**
<br>
・Alice配列<br>
・MXスイッチの36キー<br>
・サンドイッチマウント<br>

**同封されている部品**
<br>
１　PCB　１枚<br>
２　トッププレート　１枚<br>
３　ボトムプレート１式（４枚）<br>
４　ダイオード　４０個（予備４個を含む）<br>
５　タクトスイッチ　１個<br>
６　ネジ（M2 4mm）　　７本<br>
７　ネジ（M2 8mm）　　７本<br>
８　スペーサー（M2 10mm）　７本<br>
９　クッションゴム　４個<br>

**別途、購入が必要な部品**
<br>
１　キースイッチ　36個<br>
２　キーキャップ　36個 ※１<br>
３　pro micro １個<br>
４　コンスルー（スプリングピンヘッダ）　１組（２個）<br>
<br>
※１　キーキャップの構成は、1U×32、1.25U×2、1.5U×1、1.75U×1ですが、全て1Uキーでも構いません。<br>
　　　キーキャップのレジェンド（キーキャップ上面の印字）とキーレイアウトのキーのサイズが一致しません。<br>
　　　レジェンドよりも使い勝手のよいキーレイアウトを優先しています。<br>

**ファームウェア**
<br>
　このキーボードはQMKというキーボード用のソフトウェアで動作するようにプログラミングしています。
　従来、頒布を目的としていなかったことと、作者が非IT系であることから、自力でファームウェアを作成していません。
　 [Keyboard Firmware builder](https://kbfirmware.com/)を利用して、hexファイルを作成しました。
　[QMK Configurator](https://config.qmk.fm/#/) にプルリクする等すれば、QMKConfiguratorを使用してキーレイアウトを変更できますが、
　作者には、その力がありません。有識者の方で出来る方がいらっしゃれば、よろしくお願いします。
　（もし、出来ましたら、ご連絡いただけると、ビルドガイドに、そのことを記載したいと思います）
 <br>
 追記（令和３年１月16日）<br>
フライングオニオオハシ氏（＠oha_oha_Ohashi）によりqmk_firmwareへの公式マージがされました。そして、[QMK Configurator](https://config.qmk.fm/#/)にてキーレイアウトの変更、Jsonファイルをビルドができるようになりました。フライングオニオオハシ氏、本当にありがとうございました。<br>
<br>
　ここでは、Keyboard Firmware Builderで作成した、デフォルトJsonファイル（cool836default.json）とデフォルトHexファイル（cool836default.hex）を下記のリンク先に置きます。ダウンロードして、QMK Toolboxにて使用してください。QMK Toolboxは下記のリンク先にあります。<br>
　[QMK Toolbox](https://github.com/qmk/qmk_toolbox/releases)
　[デフォルトhexファイル](https://github.com/telzo2000/cool836A/)
　[デフォルトJsonファイル](https://github.com/telzo2000/cool836A/)
<br>
　QMK Toolboxの使い方は詳しく書きませんが、デフォルトhexファイルをダウンロードして、「Local File」で選択してください。pro microをPCに接続し、リセットボタンを押して書き込みます。（リセットボタンをダブルクリックしないと書き込めないパターンのものもあります）<br>
　書き込み方法などは[サリチル酸さんの（初心者編）自作キーボードにファームウェアを書き込むの記事](https://salicylic-acid3.hatenablog.com/entry/qmk-configurator)がとても参考になります。他にも有用な記事が多いので、一読することをお勧めします。<br>
<br>
　デフォルトキーマップは作者が実際に使用しているもので、ほぼ何不自由なく使えるように工夫しています。<br>
チートシートは次のとおりです。<br>
<br><br>
Layer=0<br>
cool836Alayer0

Layer=1<br>
cool836Alayer1

Layer=2<br>
cool836Alayer2

Layer=3<br>
cool836Alayer3

　キーレイアウトの変更をされる場合は、事前に、[デフォルトJsonファイル](https://github.com/telzo2000/cool836A/)をダウンロードしてから、[Keyboard Firmware builder](https://kbfirmware.com/)へアクセスしてください。「Upload」をクリックして、先ほどのデフォルトJsonファイルを選択してください。<br>
下の画面になりましたら、「KEYMAP」をクリックしてください。その画面でキーレイアウトの変更ができます。<br>

kfbscreenshot1
（「WIRING」「PINS」は絶対に変更しないでください。ここを変更して作成したHexファイルでは正しくキーが入力されなくなります。）
変更ができましたら、「SETTING」をクリックしてください。下の画面になりましたら、「Save Configuration」をクリックしてください。変更されたキーレイアウトのJsonファイルがダウンロードされます。次回以降、それを使うことで、変更履歴を意識しながら、最高のキーレイアウトへ到着できると思います。<br>

kfbscreenshot2
続いて、「COMPILE」をクリックしてください。下の画面になりましたら、「Download .hex」をクリックしてください。変更されたキーレアウトのHexフィルがダウンロードされます。このHexファイルを前述のQMK Toolboxで使用してください。<br>
kfbscreenshot3

**組み立て手順**
<br>
１　基板の確認<br>
　組み立ての前に、PCB、トッププレート、ボトムプレート１式の上・下面を確認します。全ての基板表面の右上に「cool836A」と印刷されています。印刷されている面が、上面となります。同じ位置になるように基板を重ねてください。上・下面が違うと、ネジが正しく入りません。<br>
<br>
２　ダイオードのハンダ付け<br>
　ダイオードの足を曲げて取り付けて、ハンダ付けをします。ダイオードの足は、下面から「diode」と印刷された部分の穴に差し込みます。上面に伸びたダイオードの足は切り離してください。ダイオードには極性があります。ダイオードの黒い帯がある側が「diode」の文字の後ろになるようにハンダ付けしてください。<br>


３　タクトスイッチの取り付け<br>
　タクトスイッチをPCB下面の「RESET」の印刷が隠れるように差し込んで、上面からハンダ付けをしてください。ここは上・下面を間違えると、後でトッププレートをつける時に、タクトスイッチが干渉します。
<br><br>
４　pro microの取り付け<br>
　本製品ではコンスルー（スプリングピンヘッダ）を使用してのpro microの装着を推奨しています。コンスルー（スプリングピンヘッダ）の向きに気をつけて使用してください。画像を参考にして、pro microの向きに注意してください。<br>

　コンスルーを使用しない時（pro micro付属のピンヘッダを使用する時）は、キースイッチの取り付け前に、PCBにピンヘッダのハンダ付けをしてください。キースイッチを取り付けた後では、できません。<br>

５　キースイッチの取り付け<br>
　最初にキースイッチ５個をトッププレートの５箇所（四隅と一番手前）に差し込みます。一度に全部のキースイッチを取り付けて、その後にPCBに差し込むとうまくいかないことが予想されます。５箇所で一度PCBに差し込み、ハンダ付けをしてから、残りのキースイッチをトッププレート、PCBの順に差し込み、ハンダ付けをしてください。半田付けをする前に、それぞれのキースイッチの足がきちんとPCBの基板の穴から出ていることを確認してください。差し込むときに、足が曲がってしまうことがあります。その場合は、一度キースイッチを外して、足の修正または新しいキースイッチに交換等対処してください。<br>





６　トッププレート、スペーサーの取り付け<br>
　トッププレート上面7箇所のネジ穴からM2ネジ4mm（短い方のネジ）を差し込み、スペーサーで固定します。<br>


７　ボトムプレートの取り付け<br>
　ボトムプレート1式は次の４つパーツで構成されています。<br>
　・ボトムプレート大　１枚<br>
　・ボトムプレート小　３枚<br>
　ボトムプレートのネジ穴からM2ネジ8mm（長い方のネジ）を差し込み、トッププレートに装着されているスペーサーで固定します。<br>
　このキーボードは、ボトムプレート小を１〜３枚使用することで、最大10度ぐらいの傾斜を付けることができます。また、ボトムプレート小を使わないと、傾斜のないフラットなキーボードになります。試してみて、最適な角度で使用してください。<br>

その後、お好みでクッションゴムを取り付けてください。<br>
<br>
組み立ての手順は、以上です。<br>

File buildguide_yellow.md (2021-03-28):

# イエローバージョン　ビルドガイド

**写真**

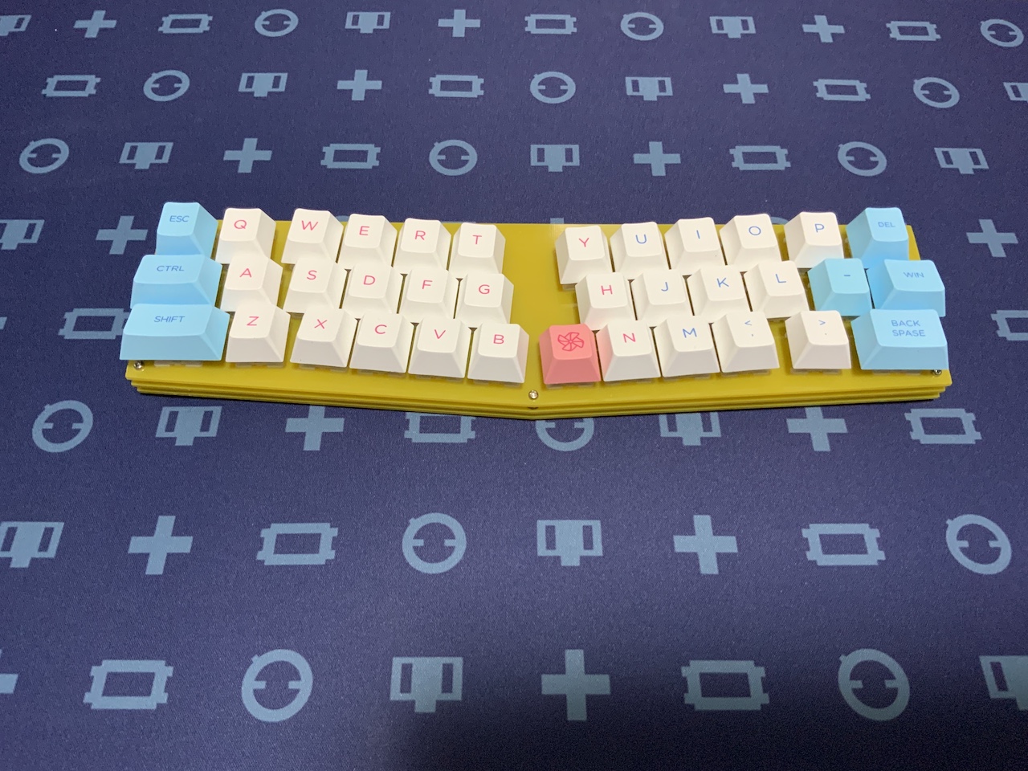
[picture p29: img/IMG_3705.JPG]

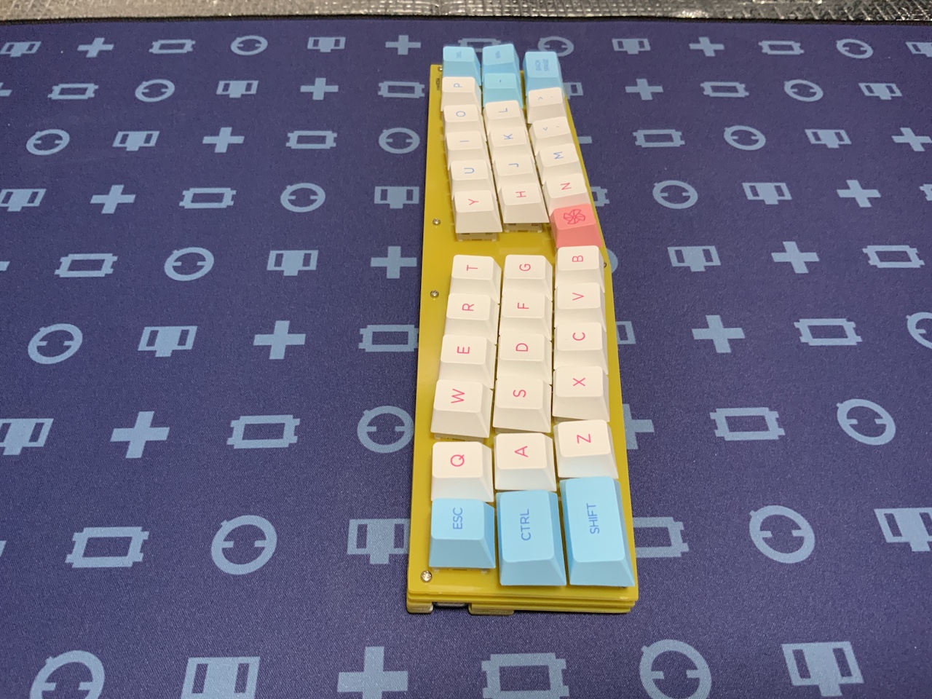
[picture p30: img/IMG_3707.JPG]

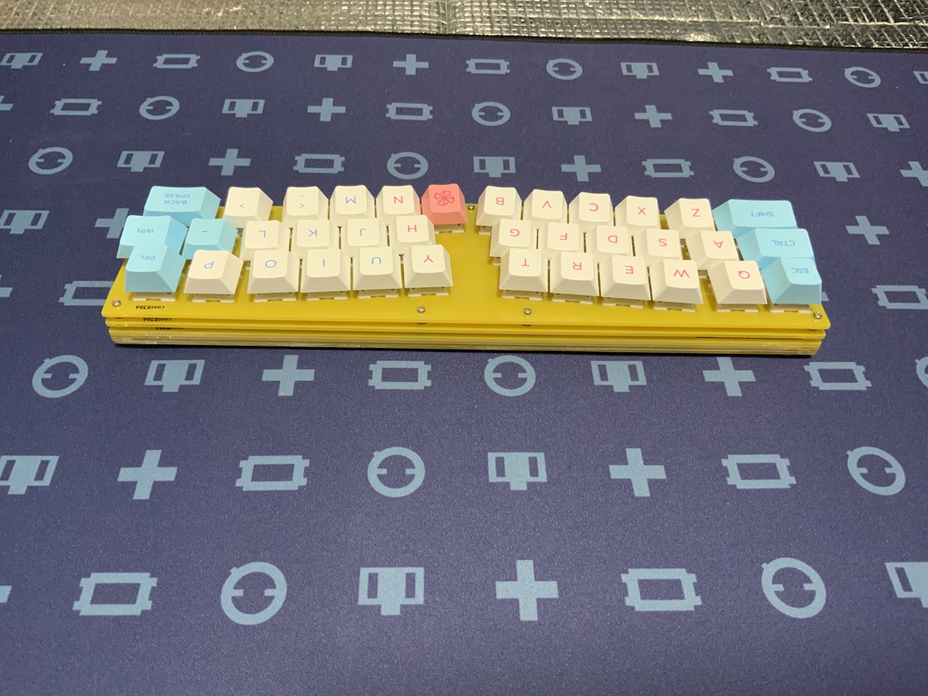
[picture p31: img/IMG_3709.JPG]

<br>
<br>
**特徴**
<br>
・30％Alice  layout<br>
・サンドイッチマウント、チル約10度<br>
・PCB、トッププレート、ボトムプレートそれぞれFR4を使用。<br>
・36キー（MXソケットによるキースイッチ交換可能）<br>
・Bluetoothへの拡張性<br>
<br>

**注意**
<br>
　cool836Aイエローバージョンは、Ver.A（通称[ブラックバージョン](https://mki0002ozlet.booth.pm/items/2408319)）、MXソケット対応（LED端子もオプション対応）のVer.B+（通称[レッドバージョン](https://mki0002ozlet.booth.pm/items/2542223)）に続く、Ver. C+として設計されました。これまでのものとの主な違いは、次の通りです。<br>
１　pro microの設置位置の変更<br>
２　１に伴い、ボトムプレートの変更<br>
３　ボトムプレート「[BLE Micro Pro用電池基板](https://yushakobo.jp/shop/ble-micro-pro-battery-board/)」を収納するスペースを追加<br>
　これらの変更をしました。Elecrowに11月14日発注して、相手側の都合により私の手元に届いたのは12月13日でした。その後、仮組みをして次の問題点が見つかりました。<br>
４　pro microの設置位置のミス。コンスルーの片側がキースイッチ底部に接触する問題。<br>
５　細身のUSB端子でないと挿し込めない。pro microにUSBケーブルを差し込む部分のケースが狭かった。<br>
　問題４については、次のことで解決しています。コンスルーが完全に挿さりませんが、動作に問題はありません。私は[Elite-C](https://yushakobo.jp/shop/elite-c/)（USB type-Cのpro micro、もげにくい）を[MAC8コンスルー](https://yushakobo.jp/shop/a01mc-00/)（スプリングピンヘッダ）で接続しています。カバンに入れて自宅と仕事場で持ち歩いて、外れてしまうかどうか確認していますが、１週間程度実施した中で、外れて接触不良を起こしたことはありません。仮に外れた場合も、ネジを外してボトムプレートを取り外して、pro microを挿し直すだけです。<br>
　問題５については、USBケーブルの端子先端が細身のものであれば、挿入に問題ありません。私はpro microもげ対策で、マグネットタイプの取り外しが容易なUSBケーブルを用いています。そのケーブルや一般的なケーブルですと、挿入できません。次の方法で解決しています。やすりで挿し込み部分のケースを削ります。削ることによって細身ではないケーブルでも挿入を問題なく行えます。元々、挿入部分が狭いので、容易にケーブルが上下左右に振られることがないため、pro microがもげにくくなっています。<br>
　問題４及び５から、これまでの[ブラックバージョン](https://mki0002ozlet.booth.pm/items/2408319)や[レッドバージョン](https://mki0002ozlet.booth.pm/items/2542223)と同じような形での頒布は購入者に混乱をもたらす可能性があると考えました。ただ、余った基板を頒布する理由には、今後の開発費を回収する目的でもあります。そのため、Elecrowから届いた基板と少量の入手が面倒と思われるM2スペーサーを必要数のみ、頒布することとしました。別途必要なものはリスト化しました。自作キーボードの部品を取り扱っているお店やネット通販で比較的入手可能と思われます。<br>
　ビルドガイドを一読して、問題ないと思われた方のみ、イエローバージョンをご購入をお願いします。ブラックバージョンやレッドバージョンに対して安価という理由で、イエローバージョンをご購入されますと、ちょっとご苦労されると思います。将来的には、３つのバージョンで培ったノウハウを元に、新バージョンを頒布する予定です。
<br>

**同封されている部品**
<br>
１　PCB　１枚<br>
２　トッププレート　１枚<br>
３　ボトムプレート１式（４枚）<br>
４　スペーサー（M2 ８mm）　７本<br>

**別途、購入が必要な部品**
<br>
１　ダイオード　36個<br>
２　タクトスイッチ　１個<br>
３　ネジ（M2 4mm）　10本<br>
４　ネジ（M2 8mm）　６本<br>
５　ナット（M2）　２個<br>
６　クッションゴム　４個<br>
７　MXソケット　36個<br>
８　キースイッチ　36個<br>
９　キーキャップ　36個 ※１<br>
10　pro micro １個<br>
11　コンスルー（スプリングピンヘッダ）　１組（２個）<br>
※１　キーキャップの構成は、1U×32、1.25U×2、1.5U×1、1.75U×1ですが、全て1Uキーでも構いません。<br>
　　　キーキャップのレジェンド（キーキャップ上面の印字）とキーレイアウトのキーのサイズが一致しません。<br>
　　　レジェンドよりも使い勝手のよいキーレイアウトを優先しています。<br>
　　　<br>
**ファームウェア**
<br>
　このキーボードはQMKというキーボード用のソフトウェアで動作するようにプログラミングしています。<br>
　従来、頒布を目的としていなかったことと、作者が非IT系であることから、自力でファームウェアを作成していません。[Keyboard Firmware builder](https://kbfirmware.com/)を利用して、hexファイルを作成しました。[QMK Configurator](https://config.qmk.fm/#/)にプルリクする等すれば、QMKConfiguratorを使用してキーレイアウトを変更できますが、作者には、その力がありません。有識者の方で出来る方がいらっしゃれば、よろしくお願いします。<br>
　（もし、出来ましたら、ご連絡いただけると、ビルドガイドに、そのことを記載したいと思います）<br>
<br>
追記（令和３年１月16日）<br>
フライングオニオオハシ氏（＠oha_oha_Ohashi）によりqmk_firmwareへの公式マージがされました。そして、[QMK Configurator](https://config.qmk.fm/#/)にてキーレイアウトの変更、Jsonファイルをビルドができるようになりました。フライングオニオオハシ氏、本当にありがとうございました。<br>
<br>
　ここでは、Keyboard Firmware Builderで作成した、デフォルトJsonファイル（cool836default.json）とデフォルトHexファイル（cool836default.hex）を下記のリンク先に置きます。ダウンロードして、QMK Toolboxにて使用してください。QMK Toolboxは下記のリンク先にあります。<br>
　[QMK Toolbox](https://github.com/qmk/qmk_toolbox/releases)
<br>
　[デフォルトhexファイル](https://github.com/telzo2000/cool836A/)
<br>
　[デフォルトJsonファイル](https://github.com/telzo2000/cool836A/)
　<br>
　QMK Toolboxの使い方は詳しく書きませんが、デフォルトhexファイルをダウンロードして、「Local File」で選択してください。pro microをPCに接続し、リセットボタンを押して書き込みます。（リセットボタンをダブルクリックしないと書き込めないパターンのものもあります）<br>
　書き込み方法などは[サリチル酸さんの（初心者編）自作キーボードにファームウェアを書き込むの記事](https://salicylic-acid3.hatenablog.com/entry/qmk-configurator)がとても参考になります。他にも有用な記事が多いので、一読することをお勧めします。<br>
　デフォルトキーマップは作者が実際に使用しているもので、ほぼ何不自由なく使えるように工夫しています。チートシートは次のとおりです。<br>
Layer=0<br>
cool836Alayer0
<br>
Layer=1<br>
cool836Alayer1
<br>
Layer=2<br>
cool836Alayer2
<br>
Layer=3<br>
cool836Alayer3
<br>
　キーレイアウトの変更をされる場合は、事前に、[デフォルトJsonファイル](https://github.com/telzo2000/cool836A/)をダウンロードしてから、[Keyboard Firmware builder](https://kbfirmware.com/)へアクセスしてください。「Upload」をクリックして、先ほどのデフォルトJsonファイルを選択してください。下の画面になりましたら、「KEYMAP」をクリックしてください。その画面でキーレイアウトの変更ができます。<br>
kfbscreenshot1
<br>
　（「WIRING」「PINS」は絶対に変更しないでください。ここを変更して作成したHexファイルでは正しくキーが入力されなくなります。）変更ができましたら、「SETTING」をクリックしてください。下の画面になりましたら、「Save Configuration」をクリックしてください。変更されたキーレイアウトのJsonファイルがダウンロードされます。次回以降、それを使うことで、変更履歴を意識しながら、最高のキーレイアウトへ到着できると思います。<br>
kfbscreenshot2
<br>
　続いて、「COMPILE」をクリックしてください。下の画面になりましたら、「Download .hex」をクリックしてください。変更されたキーレアウトのHexフィルがダウンロードされます。このHexファイルを前述のQMK Toolboxで使用してください。<br>
kfbscreenshot3
<br>
<br>
**LEDについて**
<br>
　実装できるように、PCB下面に配線はしました。動作確認はしていまん。自己責任でお願いします。レッドバージョンに実装した際、イエローバージョンでも実装を試しました。PCBとボトムプレート大の間が狭いため、工夫しないとレッドバージョンのように簡単に実装できません。解決策としては、M２スペーサー８mmと10mmに交換して、PCBとボトムプレート大の間を広げます。全体が２mm高くなります。高さについては、ボトムプレート小を１枚取り除くことが可能となります。プレートは1.6mmなので、スペーサーの交換、ボトムプレート小の取り除きで、実質0.4mm高くなることで、LEDが実装できると思います。LED対応のJsonファイルとHexファイルは[ここ](https://github.com/telzo2000/cool836A)にあります。<br>
<br>
**Bluetoothについて**
<br>
　せきごん氏が開発された「[BLE Micro Pro Type-C版](https://yushakobo.jp/shop/ble-micro-pro/)」と「[BLE Micro Pro用電池基板](https://yushakobo.jp/shop/ble-micro-pro-battery-board/)」を設置できるようボトムプレートの見直しをしました。ボトムプレートの一部パーツを切り離すことで「BLE Micro Pro用電池基板」を収納できます。動作確認はしていません。自己責任でお願いします。
<br>
<br>
**組み立て手順**
<br>
１　基板の確認<br>
　組み立ての前に、PCB、トッププレート、ボトムプレート１式の上・下面を確認します。全ての基板表面の右上に「cool836A」と印刷されています。印刷されている面が、上面となります。同じ位置になるように基板を重ねてください。上・下面が違うと、ネジが正しく入りません。<br>
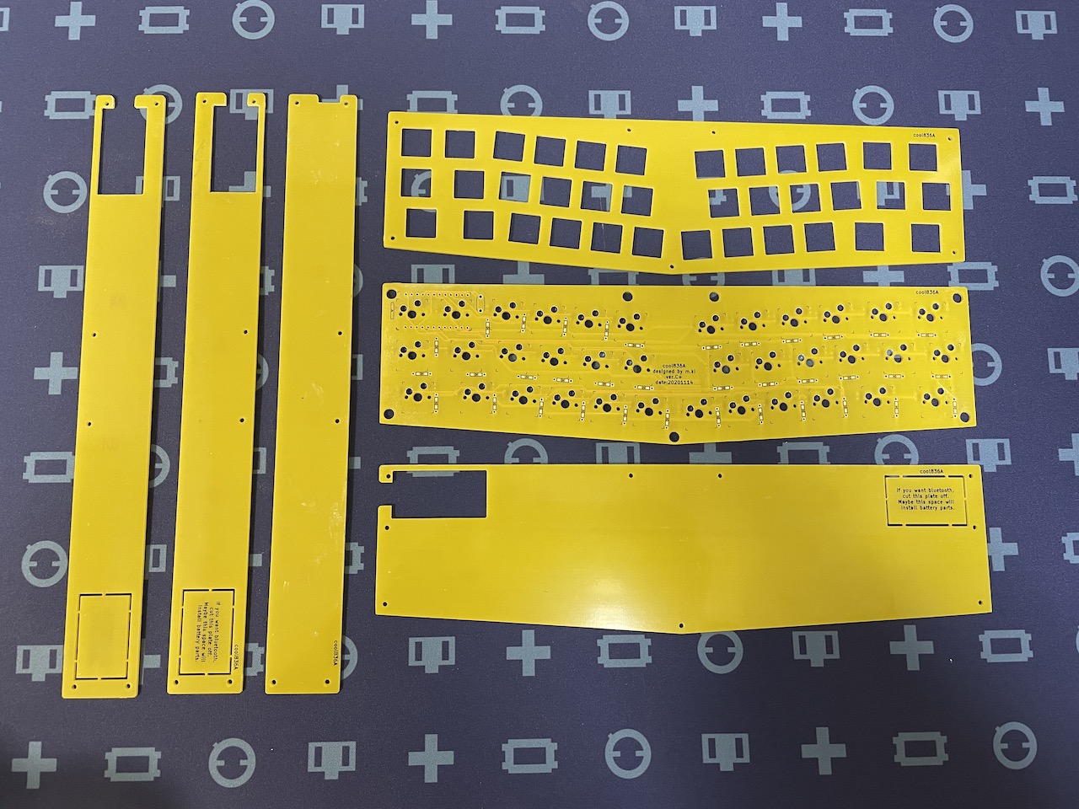
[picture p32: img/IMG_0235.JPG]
基板
　
　<br>
２　ダイオードのハンダ付け<br>
　ダイオードの足を曲げて取り付けて、ハンダ付けをします。ダイオードの足は、下面から「diode」と印刷された部分の穴に差し込みます。ダイオードをマスキングテープ等で仮止めして、基板を裏側にして上面に伸びたダイオードの足は切り離してください。ダイオードには極性があります。ダイオードの黒い帯がある側が「diode」の文字の後ろになるようにハンダ付けしてください。ハンダ付けに自信がない場合、フラックスを利用すると、上手にハンダ付けができます。その後、フラックスクリーナーで綺麗に拭き取ることをお勧めします。<br>
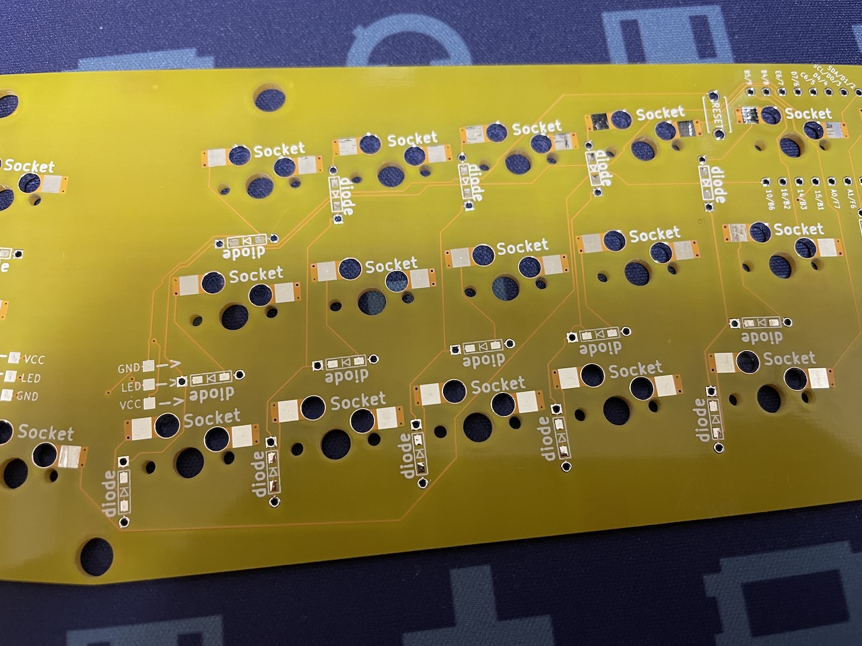
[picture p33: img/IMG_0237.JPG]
ダイオード

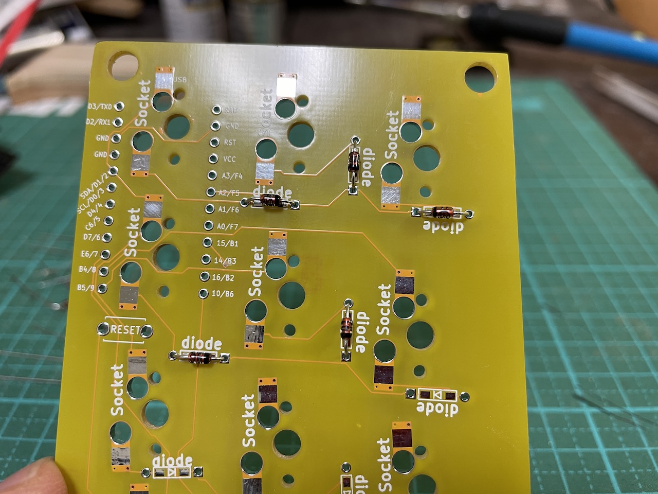
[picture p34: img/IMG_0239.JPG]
ダイオードハンダ付け

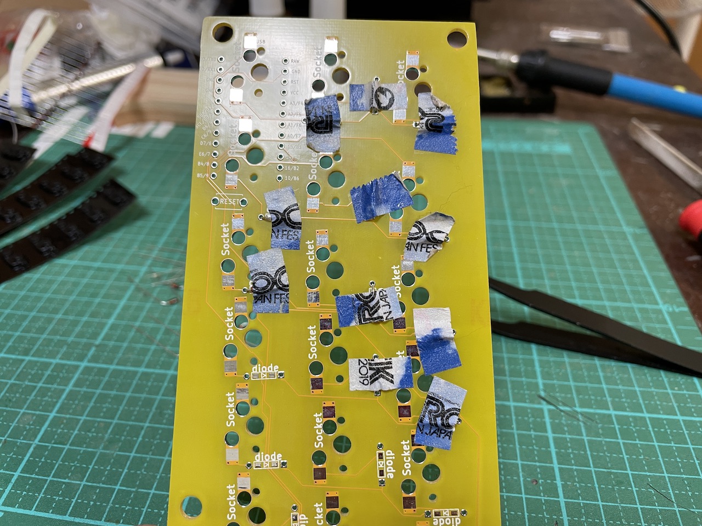
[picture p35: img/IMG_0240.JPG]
仮止め

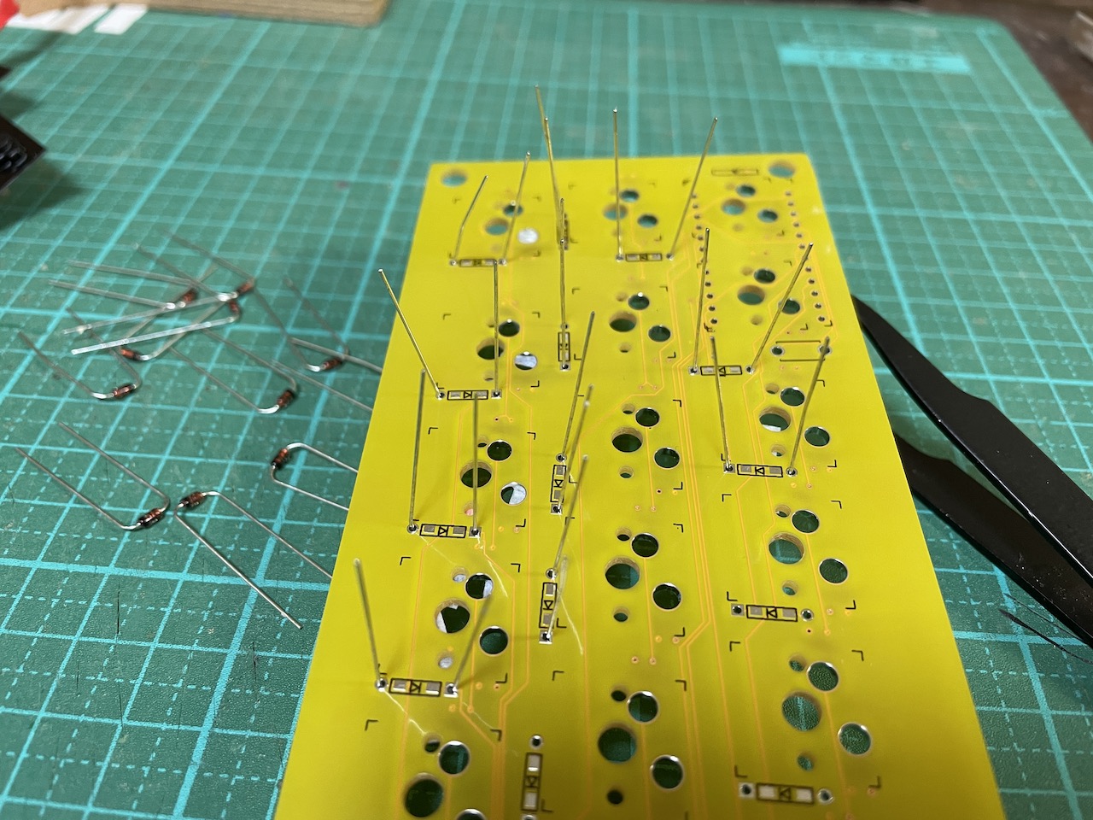
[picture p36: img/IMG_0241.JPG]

ダイオードハンダ付け２
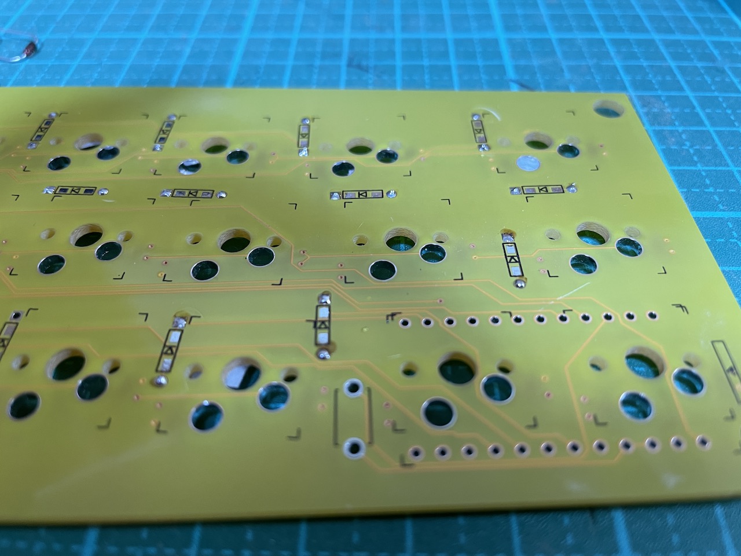
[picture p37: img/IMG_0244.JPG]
<br>
<br>
３　MXソケットのハンダ付け<br>
　MXソケットをハンダ付けします。ソケットの向きに注意してください。基板にはSocketと書かれています。文字が隠れるようにソケットを置いてください。ソケット両側の端子がPCBと接する方に、予備ハンダをしておくと、ハンダ付けが上手くいきます。上手くハンダ付けができない場合、フラックスを多めに塗布して行うと、ハンダがソケットの端子とPCBの端子の間に流れていきます。その後、フラックスクリーナーで綺麗に拭き取ることをお勧めします。<br>
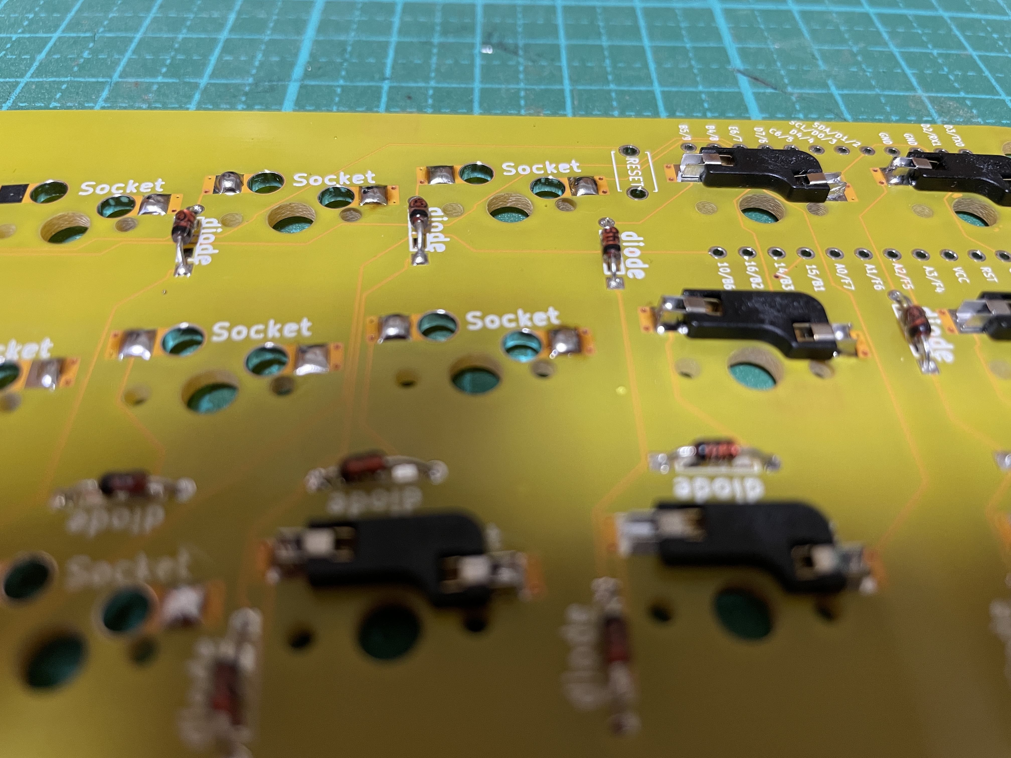
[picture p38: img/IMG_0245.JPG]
ソケットハンダ付け

　<br>

４　タクトスイッチの取り付け<br>
　タクトスイッチをPCB下面の「RESET」の印刷が隠れるように差し込んで、上面からハンダ付けをしてください。ここは上・下面を間違えると、後でトッププレートをつける時に、タクトスイッチが干渉します。<br>
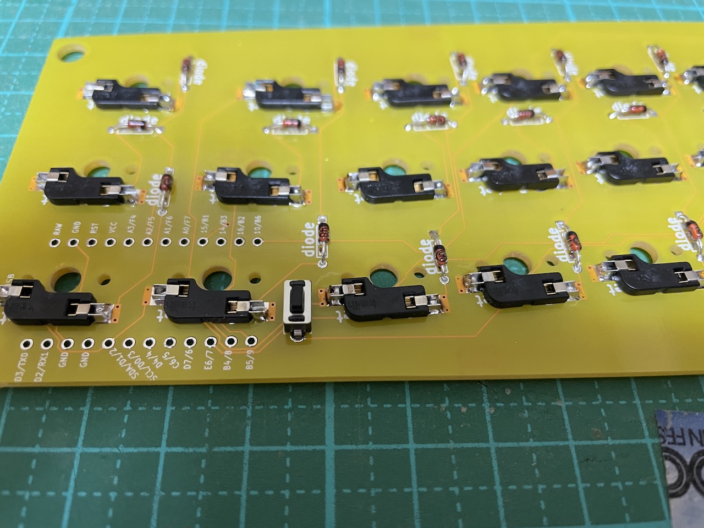
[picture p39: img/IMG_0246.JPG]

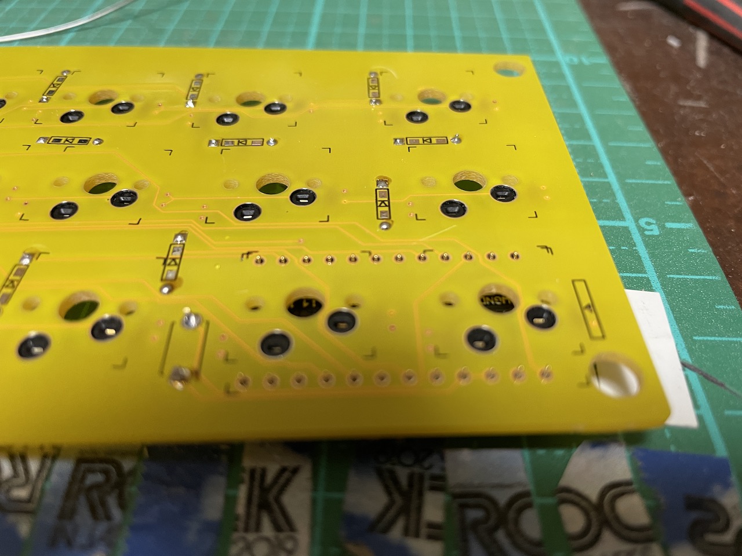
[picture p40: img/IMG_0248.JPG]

　<br>

５　pro microの取り付け①<br>
　本製品ではコンスルー（スプリングピンヘッダ）を使用してのpro microの装着を推奨しています。コンスルー（スプリングピンヘッダ）の向きに気をつけて使用してください。画像を参考にして、pro microの向きに注意してください。イエローバージョンではこれまでバージョンと違い、pro microの向きが逆になります。平な面からコンスルーを挿します。
<br>






<br>
　コンスルーを使用しない時（pro micro付属のピンヘッダを使用する時）は、キースイッチの取り付け前に、PCBにピンヘッダのハンダ付けをしてください。キースイッチを取り付けた後では、できません。その際、ダイオードの足を切り離すように、PCBからはみでたピンヘッダを切り離してください。これをしないと、一部のキースイッチがうまく挿し込めません。<br>
　<br>
　<br>
６　pro microの取り付け②<br>
　問題４に関する部分です。コンスルーを使用した場合、pro microは写真のようにしか挿さりません。<BR>


<br>
　片側が浮いてしまいます。ただ、この状態でも接触しているので、動作に支障がありません。心配と感じる方は、コンスルーではなく、pro microに付属しているピンヘッダで半田付けをすれば、大丈夫です。<br>

７　キースイッチの取り付け<br>
　最初にキースイッチ５個をトッププレートの５箇所（四隅と一番手前）に差し込みます。一度に全部のキースイッチを取り付けて、その後にPCBにハンダ付けしたMXソケットに差し込むとうまくいかないことが予想されます。５箇所で一度PCBにハンダ付けしたMXソケットに差し込み、残りのキースイッチをトッププレート、PCBの順に差し込んでください。それぞれのキースイッチの足がきちんとMXソケットの基板の穴に差し込まれていることを確認してください。差し込むときに、足が曲がってしまうことがあります。その場合は、ボタンを押しても入力されません。一度キースイッチを外して、足の修正または新しいキースイッチに交換等対処してください。
<br>



<br>
８　ボトムプレートの取り付け<br>
　ボトムプレート1式は次の４つパーツで構成されています。<br>
　・ボトムプレート大　１枚<br>
　・ボトムプレート小　３枚（pro micro収納のため、くり抜きがあるもの２、ないもの１）
<br>
　ボトムプレート小３枚を重ね合わせます。「cool836A」と書かれている面が上面です。一番下から、pro micro収納のためのくり抜きのないもの、くり抜きのあるもの、くり抜きのあるものの順で重ねて、その上にボトムプレート大を合わせて、６箇所を下のネジ穴からM２ネジ８mm（長い方のネジ）を差し込み、ボトムプレート上面から、M２ナット２箇所、M２スペーサー８mmで締めます。下の写真のようになります。<br>


<br>
　問題５については、細身のUSBケーブルを使用するならば、大丈夫ですが、一般的な幅を持つものであれば、次の写真のようにやすりで拡幅する必要がありす。
<br>











<br>
　その後、ボトムプレート大の下面から残り３箇所のネジ穴に、M２ネジ４mmを挿しこみ、M２スペーサー８mmで締めます。
<br>


<br>
<br>

９　トッププレートの取り付け<br>
　トッププレート上面7箇所のネジ穴からM2ネジ4mm（短い方のネジ）を差し込み、スペーサーで固定します。<br>



<br>
　その後、クッションゴムを取り付けてください。底面がフラットではないため、クッションゴムの使用が前提となります。クッションゴムは高さが５mm程度あるものをご利用ください。それより低いものですと、底面の段差に影響されて、適切なポジションが取りにくくなります。<br>
<br>
　組み立ての手順は、以上です。<br>
<br>
　最後に、お気に入りのキーキャップを装着したら、完成です。<br>
　気に入っていただけたら、幸いです。<br>
<br>

***おまけ***
<br>
　ボトムプレートにある、下の写真の部分を必要な枚数切り離しますと、「
BLE Micro Pro用電池基板」が装着できる空間が確保できます。切り離す枚数は、ご自身でご確認ください。また、配線処理についても同様に、自己責任でお願いします。<br>



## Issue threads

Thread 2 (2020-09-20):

build guide for cool836A

telzo2000, 2020-09-20:
特徴
・Alice配列
・MXスイッチの36キー
・インテグレートマウント

同封されている部品
１　PCB　１枚
２　トッププレート　１枚
３　ボトムプレート１式（４枚）
４　ダイオード　４０個（予備４個を含む）
５　タクトスイッチ　１個
６　ネジ（M2 4mm）　　７本
７　ネジ（M2 8mm）　　７本
８　スペーサー（M2 10mm）　７本
９　クッションゴム　４個

別途、購入が必要な部品
１　キースイッチ　36個
２　キーキャップ　36個 ※１
３　pro micro １個
４　コンスルー（スプリングピンヘッダ）　１組（２個）

※１　キーキャップの構成は、1u×32、1.25U×2、1.5U×1、1.75U×1ですが、全て1Uキーでも構いません。
　　　キーキャップのレンジェンドとキーレイアウトのキーのサイズが一致しません。
　　　レジェンドよりもキーレイアウトを優先しています。

ファームウェア

組み立て手順

１　基板の確認
　組み立ての前に、PCB、トッププレート、ボトムプレート１式の上・下面を確認します。全ての基板表面の右上に「cool836A」と印刷されています。印刷されている面が、上面となります。同じ位置になるように基板を重ねてください。上・下面が違うと、ネジが正しく入りません。

２　ダイオードのハンダ付け
　ダイオードの足を曲げて取り付けて、ハンダ付けをします。ダイオードの足は、下面から「diode」と印刷された部分の穴に差し込みます。上面に伸びたダイオードの足は切り離してください。ダイオードには極性があります。ダイオードの黒い帯がある側が「diode」の文字の後ろになるようにハンダ付けしてください。
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

３　タクトスイッチの取り付け
　タクトスイッチをPCB下面の「RESET」の印刷が隠れるように差し込んで、上面からハンダ付けをしてください。ここは上・下面を間違えると、後でトッププレートをつける時に、タクトスイッチが干渉します。

４　pro microの取り付け
　本製品ではコンスルー（スプリングピンヘッダ）を使用してのpro microの装着を推奨しています。コンスルー（スプリングピンヘッダ）の向きに気をつけて使用してください。画像を参考にして、pro microの向きに注意してください。
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
　コンスルーを使用しない時（pro micro付属のピンヘッダを使用する時）は、キースイッチの取り付け前に、PCBにピンヘッダのハンダ付けをしてください。キースイッチを取り付けた後では、できません。

５　キースイッチの取り付け
　最初にキースイッチ５個をトッププレートの５箇所（四隅と一番手前）に差し込みます。一度に全部のキースイッチを取り付けて、その後にPCBに差し込むとうまくいかないことが予想されます。５箇所で一度PCBに差し込み、ハンダ付けをしてから、残りのキースイッチをトッププレート、PCBの順に差し込み、ハンダ付けをしてください。半田付けをする前に、それぞれのキースイッチの足がきちんとPCBの基板の穴から出ていることを確認してください。差し込むときに、足が曲がってしまうことがあります。その場合は、一度キースイッチを外して、足の修正または新しいキースイッチに交換等対処してください。
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

６　トッププレート、スペーサーの取り付け
　トッププレート上面7箇所のネジ穴からM2ネジ4mm（短い方のネジ）を差し込み、スペーサーで固定します。
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

７　ボトムプレートの取り付け
　ボトムプレート1式は次の４つパーツで構成されています。
　・ボトムプレート大　１枚
　・ボトムプレート小　３枚
　ボトムプレートのネジ穴からM2ネジ8mm（長い方のネジ）を差し込み、トッププレートに装着されているスペーサーで固定します。
　このキーボードは、ボトムプレート小を１〜３枚使用することで、最大10度ぐらいの傾斜を付けることができます。また、ボトムプレート小を使わないと、傾斜のないフラットなキーボードになります。試してみて、最適な角度で使用してください。
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
その後、お好みでクッションゴムを取り付けてください。
組み立ての手順は、以上です。

telzo2000, 2020-09-20:
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

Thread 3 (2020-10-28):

SU120を使っての試作

telzo2000, 2020-10-28:
Alice配列で30%キーボードを構想したのは、nomu30を使い始めた影響である。nomu30はとても良い30%キーボードである。私の使用する環境において、日本語を入力することがほぼ100％なため、句読点と長音記号をレイヤー下に置くのは、不便であった。その句読点、長音記号を配列に加えた30％キーボードを構想したが、ややデザイン上、気に入らなかった。cool836Aを構想した際、句読点と長音記号のキーを加えても、デザイン上破綻しないことがわかった。そのため、SU120を使い、試作品を作ろうと考えた。
![ 97398189 をアップロード中...]

配列については、KeyboardLayoutEditerを使い、

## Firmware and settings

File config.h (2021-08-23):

#ifndef CONFIG_H
#define CONFIG_H

#include "config_common.h"

/* USB Device descriptor parameter */
#define VENDOR_ID       0xFEED
#define PRODUCT_ID      0x6060
#define DEVICE_VER      0x0001
#define MANUFACTURER    m.ki
#define PRODUCT         cool836A
#define DESCRIPTION     Keyboard

/* key matrix size */
#define MATRIX_ROWS 6
#define MATRIX_COLS 6

/* key matrix pins */
#define MATRIX_ROW_PINS { F5, D0, B2, C6, D7, E6 }
#define MATRIX_COL_PINS { D1, B5, B4, F4, B1, B6 }
#define UNUSED_PINS

/* COL2ROW or ROW2COL */
#define DIODE_DIRECTION COL2ROW 

/* number of backlight levels */

#ifdef BACKLIGHT_PIN
#define BACKLIGHT_LEVELS 0
#endif

/* Set 0 if debouncing isn't needed */
#define DEBOUNCING_DELAY 5

/* Mechanical locking support. Use KC_LCAP, KC_LNUM or KC_LSCR instead in keymap */
#define LOCKING_SUPPORT_ENABLE

/* Locking resynchronize hack */
#define LOCKING_RESYNC_ENABLE

/* key combination for command */
#define IS_COMMAND() ( \
    keyboard_report->mods == (MOD_BIT(KC_LSHIFT) | MOD_BIT(KC_RSHIFT)) \
)

/* prevent stuck modifiers */
#define PREVENT_STUCK_MODIFIERS

#define RGB_DI_PIN D3
#ifdef RGB_DI_PIN
#define RGBLIGHT_ANIMATIONS
#define RGBLED_NUM 6
#define RGBLIGHT_HUE_STEP 8
#define RGBLIGHT_SAT_STEP 8
#define RGBLIGHT_VAL_STEP 8
#endif

#endif

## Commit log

2020-10-02 自作データの保存場所をgithubへ
    [cool836.GBL, cool836.GBO, cool836.GBS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]
2020-11-14 20201115 追記
2020-11-24 20201124追記
2020-11-24 Update buildguide_red.md
    20201124完成
2020-12-17 Update README.md
    20201217追記
2020-12-22 サイズ変更
2020-12-23 拡張子修正
2020-12-26 Update README.md
    いえろバージョンのビルドガイド部分を追記
2020-12-28 Update README.md
    追記20201228
2021-01-15 qmk対応について追記
2021-01-15 qmk_configurator用Jsonファイル
2021-01-18 新規作成
